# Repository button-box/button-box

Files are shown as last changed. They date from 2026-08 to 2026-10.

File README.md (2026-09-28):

# Button Box

Illustrated Button Box with a glowing blue button and family portraits

> **[Join the Button Box WhatsApp community →](https://chat.whatsapp.com/FJ8LYL79k8zEMfoiyPjLPb?mode=gi_t)**
>
> Meet other builders, share progress, and help shape the project.

**Button Box is a screen-free way for kids to send and receive WhatsApp voice
messages with family on their own.**

Button Box is an open-source hardware and software project built around one
large illuminated button. A child can record a voice note and send it to an
approved person or group. Incoming replies wait on the box until the child
presses the button to listen.

[Visit button.box](https://button.box/) ·
[Report an issue](https://github.com/button-box/button-box/issues) ·
[Testing and regression matrix](docs/testing.md)

## Latest release

[v0.1.0](https://github.com/button-box/button-box/releases/tag/v0.1.0)
includes voice messaging, video audio, recipient routing, the caregiver dashboard
and startup recovery. Tested on Raspberry Pi 4. The source release includes
a bounded updater, an installed-code manifest and checksums. Read the
[release notes](docs/releases/v0.1.0.md) before
installation. Each assembled unit requires its own physical acceptance run
before delivery.

## Build a Button Box

The complete journey is:

1. Buy the parts.
2. Assemble the hardware.
3. Prepare a Raspberry Pi OS microSD card.
4. Download this repository.
5. Connect to and inspect the Pi.
6. Provision Button Box.
7. Link WhatsApp, choose approved recipients, and optionally pair NFC tags.
8. Test the physical hardware.
9. Send, receive, play, and repeat after a reboot.

Each detailed step below ends with a **Done when** checkpoint. If the observed
result differs, stop there and troubleshoot instead of pushing ahead.

For repeatable release and per-unit verification, use the
[canonical acceptance matrix](docs/box-acceptance.md) and its
[per-unit run template](docs/box-acceptance-run-template.md).

## Step 1 — Buy your parts

### Choose a Raspberry Pi

| Board | Current status | What to expect |
| --- | --- | --- |
| **Raspberry Pi 4B** | Recommended for a first build | The public installation path has been physically exercised through Wi-Fi and WhatsApp readiness. |
| **Raspberry Pi Zero 2 W** | Supported device target; public installation gap | It needs an OTG USB hub for the USB microphone and speaker. On current `main`, provisioning stops at the Pi-4-only Comitup installer, so the fresh-card community path still needs validation. |

Do not bypass a board-safety check on a working device. If you want to help
finish the Zero 2 W path, please join the community or open a focused pull
request with the board and physical checks you performed.

### Parts with purchase links

Two versions exist — pick the parts list that matches your enclosure:
the [US parts list](#us-parts-list) or the [European parts list](#european-parts-list).
We are not affiliated with these retailers.

#### US parts list

Choose one Pi, its matching power supply, and the shared parts below.

- **Raspberry Pi Zero 2 W:** [official product and reseller page](https://www.raspberrypi.com/products/raspberry-pi-zero-2-w/?variant=raspberry-pi-zero-2-w)
- **Or Raspberry Pi 4B:** [PiShop.US](https://www.pishop.us/product/raspberry-pi-4-model-b-1gb/), [Vilros](https://vilros.com/products/raspberry-pi-4-model-b-1), or [CanaKit](https://www.canakit.com/raspberry-pi-4.html)
- **32 GB SanDisk Ultra A1 microSD card:** [Amazon](https://www.amazon.com/dp/B08L5HMJVW/)
- **TONOR G11 USB microphone:** [Amazon](https://www.amazon.com/dp/B07GVGMW59)
- **LIELONGREN 8 W USB speaker:** [Amazon](https://www.amazon.com/dp/B08QRYTPGH)
- **Pi Zero 2 W power supply:** [official Raspberry Pi 12.5 W Micro USB Power Supply](https://www.raspberrypi.com/products/micro-usb-power-supply/)
- **Or Pi 4B power supply:** [iUniker 5 V / 4 A USB-C supply](https://www.amazon.com/dp/B097P2NLVH)
- **100 mm illuminated arcade button:** [Amazon](https://www.amazon.com/dp/B072JLSH34)
- **NFC reader:** The original NFC build uses the [HiLetgo PN532 NFC/RFID module kit](https://www.amazon.com/dp/B01I1J17LC) and needs soldering. If you do not want to solder, use a Waveshare PN532 NFC HAT instead.
- **Optional M2.5 screws, nuts, and washers:** [Amazon](https://www.amazon.com/dp/B0FJ1XN2XP) — useful for mounting the Pi or NFC board inside a custom enclosure; not required for a shoebox prototype

The US reference-parts list is approximately **$150 before the enclosure,
Zero 2 W adapters, NFC tokens, shipping, and taxes**. Retailer prices and
availability change.

This is our current US reference build. Other USB speakers and microphones, and other GPIO-connected buttons, may work electrically and with the software, but each substitution is unvalidated. The Original / US printable enclosure was designed for the parts in this list. If you change the speaker, microphone, or another part, the 3D-print designs may need a revision; do not assume the substitute will fit the same case.

#### European parts list

For the [EU S8 enclosure](hardware/enclosure/README.md) (EL001 speaker).
Full parts list: [EU BOM](hardware/enclosure/eu-el001/BOM.md).

- **Raspberry Pi 4 Model B (1 GB)**
- **32 GB microSD card**
- **HOTUT USB conference mic**
- **EL-001 USB soundbar**
- **EU USB mains supply** — 15 W USB-C recommended
- **EG STARTS 100 mm illuminated arcade button, blue:** [Amazon](https://www.amazon.com/dp/B072JLSH34)
- **Waveshare PN532 NFC HAT**
- **Full-size NFC cards**
- **Mounting fasteners, hook-up wire, and PLA feedstock** for the printed enclosure

You will also need:

- **NFC cards or tokens:** [Adafruit 13.56 MHz Classic 1K card](https://www.adafruit.com/product/359), which Adafruit states is tested with PN532 readers
- **Hook-up wire and insulated connectors:** [0.25-inch arcade-button wire pairs](https://www.adafruit.com/product/3838) and an [assorted 2.8/4.8/6.3 mm spade-connector kit](https://www.adafruit.com/product/4748) are examples; confirm the terminal sizes on your button before ordering
- **A microSD-card reader that fits your computer:** [USB-C example](https://www.adafruit.com/product/5212) or [USB-A example](https://www.adafruit.com/product/939)
- **For Pi Zero 2 W, a suitable OTG USB hub**, powered if your selected audio devices require it. This [micro-USB OTG mini hub](https://www.adafruit.com/product/2991) is an example only; it has not yet been physically validated with the reference microphone and speaker.
- **An enclosure:** use a [printable enclosure](hardware/enclosure/README.md) — available in US and European versions, each with its own parts list — a shoebox, or another sturdy, non-conductive container.
- **A computer with internet access** for preparing and provisioning the Pi
- **A new, dedicated phone number for the Button Box WhatsApp account.** Add a line or eSIM through your mobile provider, activate it in the WhatsApp mobile app on a phone, and then link Button Box as a companion device.

### What the build takes

- Comfort following terminal commands one step at a time, or access to an AI
  coding agent that can guide you
- Raspberry Pi Imager and permission to erase a microSD card
- Temporary Wi-Fi, Ethernet, USB Ethernet, or Internet Sharing during setup
- Time to assemble, install, test each component, and troubleshoot an alpha
  build

> [!NOTE]
> The public product is **Button Box**. Some commands, package names, hostnames,
> and services still use the historical internal name `messagebox`. Use those
> exact names for now.

### Once your parts arrive — build with an agent

Point a capable coding agent at this repository and give it this prompt:

```text
Help me build a Button Box from this repository:
https://github.com/button-box/button-box

Read README.md and AGENTS.md before giving instructions. First ask whether I
have a Raspberry Pi Zero 2 W or Raspberry Pi 4B. Work one numbered step at a
time and wait for me to confirm each physical result.

The goal is to have a working box that sends and receives voice messages.
Do not ask me to paste credentials, phone numbers, WhatsApp identifiers, Wi-Fi
details, NFC identifiers, recordings, or authentication files into the chat.
Stop if my physical result differs from the README checkpoint.
```

A helpful agent should:

- identify the Pi model before choosing parts or commands
- explain each command before asking the builder to run it
- use each **Done when** result as a checkpoint
- stop when physical evidence differs from the guide
- never guess a disk, network address, GPIO connection, or WhatsApp recipient
- preserve a working card or device rather than experimenting on it
- redact private information before helping prepare an issue

Button Box uses [wacli](https://github.com/openclaw/wacli), an unofficial
WhatsApp Web client. Button Box is not affiliated with or endorsed by WhatsApp
or Meta.

## Step 2 — Assemble the hardware

A shoebox or another sturdy, non-conductive box is an alternative to 3D printing the enclosure. Whichever enclosure you use, secure the electronics, provide ventilation, and protect the cables from strain and loose metal.

The default public GPIO configuration is:

| Connection | BCM/board name |
| --- | --- |
| Record button | BCM GPIO 17 |
| Button LED | BCM GPIO 26 |
| PN532 reset | D20 |
| PN532 request | D16 |
| PN532 data | I²C |

> [!CAUTION]
> A [community wiring diagram](hardware/README.md#community-wiring-diagram) is available,
> with different PN532 reset/request pins and configuration notes. It has not
> been physically validated. The pin list above remains the software default. Confirm button voltage, LED current limiting, connector sizes, Pi
> pin numbering, and PN532 I²C mode before applying power. Never connect or
> disconnect GPIO wiring while the Pi is powered.

For the printable prototype, download the [top](hardware/enclosure/button-box-enclosure-top.stl)
and [bottom](hardware/enclosure/button-box-enclosure-bottom.stl) enclosure files.

**Done when:** the unpowered assembly is mechanically secure, every connection
has been independently checked, and there are no loose conductors or shorts.

## Step 3 — Prepare the microSD card

Install the current [Raspberry Pi Imager](https://www.raspberrypi.com/software/)
on your computer.

In Imager:

1. Select your exact Raspberry Pi model.
2. Select **Raspberry Pi OS Lite (64-bit)** based on Debian 13.
3. Choose the correct microSD card.
4. Set a hostname such as `button-box-001`. Existing `message-box-*` hostnames remain supported.
5. Create a non-root administrator such as `admin`.
6. Enable SSH, preferably with a dedicated public key.
7. Give the Pi temporary internet access through Imager Wi-Fi settings,
   Ethernet, USB Ethernet, or Internet Sharing.
8. Leave Raspberry Pi Connect disabled unless you deliberately need it.
9. Confirm the exact removable card before writing.

> [!CAUTION]
> Writing an operating-system image erases the selected card. Confirm its
> physical identity, capacity, and partitions before continuing.

> [!IMPORTANT]
> Imager remembers customisation from previous runs, including the Wi-Fi network
> name and password, and pre-fills them. When re-flashing after a Pi that failed
> to appear, retype the Wi-Fi name rather than accepting the remembered value: a
> typo carries forward silently, and the retained setting is most likely to bite
> exactly when you are trying to correct it.

Insert the verified card into the powered-off Pi, connect temporary networking,
and power it on.

**Done when:** the Pi boots and responds at its `.local` hostname.

## Step 4 — Download Button Box on your computer

On the computer that will provision the Pi:

```sh
git clone https://github.com/button-box/button-box.git
cd button-box
```

Confirm the checkout and required host commands:

```sh
git status --short --branch
ssh -V
rsync --version
```

On macOS, use a modern GNU rsync rather than the built-in `openrsync`:

```sh
brew install rsync
PATH="/opt/homebrew/bin:$PATH" rsync --version
```

**Done when:** the repository is on your computer and SSH plus modern rsync are
available.

## Step 5 — Connect to and inspect the Pi

Replace `admin` and the hostname below if you chose different values:

```sh
ssh admin@button-box-001.local
```

On the Pi, verify the model, architecture, and operating-system release:

```sh
tr -d '\0' </proc/device-tree/model
uname -m
grep -E '^(PRETTY_NAME|VERSION_CODENAME)=' /etc/os-release
```

Expected architecture: `aarch64`

Expected Debian codename: `trixie`

Exit the Pi:

```sh
exit
```

**Done when:** the detected model matches your chosen board and the supported
64-bit OS is running.

## Step 6 — Install Button Box

> [!IMPORTANT]
> Continue with the automated public installer on Raspberry Pi 4B. On current
> `main`, the install stops on Pi Zero 2 W because `scripts/install/comitup.sh`
> is explicitly validated only on Pi 4. Zero 2 W runtime support remains, but
> its fresh-card installation path needs a tested repository change.

From the repository root on your computer:

```sh
./scripts/provision.sh admin@button-box-001.local
```

On macOS with Homebrew rsync:

```sh
PATH="/opt/homebrew/bin:$PATH" ./scripts/provision.sh admin@button-box-001.local
```

The script transfers an explicit set of installation files, installs Button Box
in fixed system paths, and leaves runtime and onboarding services stopped.

**Done when:** setup prints `BUTTON BOX SETUP COMPLETE` without an error.

## Step 7 — Choose an onboarding path

### Path A: terminal-assisted DIY build

This is currently the shortest path to a working experimental box. It uses the
Pi's temporary network connection and does not use the consumer Wi-Fi portal.

Run from your computer:

```sh
ssh -t admin@button-box-001.local messagebox-dev-onboard
```

The guided workflow will:

1. Link or verify WhatsApp.
2. Display recent chats with their exact WhatsApp identifiers.
3. Configure the first approved recipient.
4. Optionally configure the private dashboard.
5. Offer to test the physical hardware.
6. Enable and start the selected runtime services.

Enter phone numbers and other private values directly into the terminal when
prompted. Do not paste them into an agent conversation or GitHub issue.

**Done when:** the workflow reports WhatsApp ready, the exact intended recipient
is configured, the selected hardware tests pass, and the selected services are
enabled and started.

### Path B: browser Wi-Fi and WhatsApp onboarding

This path is the intended household experience from Wi-Fi through normal
runtime activation.

Initialize the protected onboarding identity:

```sh
ssh -t admin@button-box-001.local sudo messagebox-init-wifi-onboarding
```

Record the displayed hotspot name, hotspot password, and setup URL privately.
Then arm onboarding:

```sh
ssh -t admin@button-box-001.local sudo messageboxctl reset-wifi
```

On a phone:

1. Join the Button Box setup hotspot.
2. Open the supplied setup URL.
3. Select home Wi-Fi and enter its password.
4. Rejoin home Wi-Fi when the setup hotspot disappears.
5. Open the same `http://button-box-001.local/` address.
6. Link WhatsApp with the displayed phone code.
7. Choose a default recipient and complete the guided two-way voice test.
8. Allow any additional recipients and optionally pair NFC tags.
9. Skip NFC setup or choose Done to activate messaging.

NFC is optional. A zero-tag setup routes new standalone messages to the default
recipient without depending on the reader. Once any tag is mapped, unsafe NFC
health or unknown tag state blocks rather than silently choosing the default.
Path A remains the terminal-assisted developer workflow; the two paths are not
continuations of one another.

**Done when:** the browser reports that Button Box is ready and the intended
default and optional tag mappings pass the physical scenarios below.

## Step 8 — Test the hardware

The terminal-assisted onboarding offers this test automatically. To run it
separately, connect to the Pi and run it as the `messagebox` service user:

```sh
ssh -t admin@button-box-001.local
sudo -u messagebox -H /opt/messagebox/dev/hardware-test.sh
```

The interactive test checks:

- internet access
- speaker
- microphone and playback
- button LED
- record button
- PN532 reader and an NFC card
- WhatsApp authentication

It does not send a WhatsApp message or reveal NFC identifiers.

**Done when:** every installed component passes, or any deliberately omitted
component is documented.

## Step 9 — Start the box and complete the first message loop

Check the selected services:

```sh
messageboxctl services
messageboxctl status
```

With an approved recipient expecting the test:

1. Hold the physical button and record a short message.
2. Release the button and follow the box's confirmation behavior.
3. Confirm that the message reaches the intended recipient.
4. Ask the recipient to reply with a voice note.
5. Confirm the box queues and plays the reply.
6. Reboot the Pi.
7. Repeat a short send-and-receive check.

**Done when:** the real button, LED, microphone, speaker, network, WhatsApp
account, recipient routing, send, reply, playback, and reboot behavior all pass
on the physical device.

## What works today

| Capability | Status | What that means |
| --- | --- | --- |
| Device runtime | **Experimental** | Recording, sending, receiving, playback, fail-closed recipient routing, and NFC support exist. |
| Raspberry Pi 4B | **Supported** | A brand-new-card installation has been physically completed through Wi-Fi and WhatsApp onboarding. |
| Raspberry Pi Zero 2 W | **Supported device target; install gap** | The device target is supported, but the current public provisioning path still contains a Pi-4-only Comitup gate and needs clean-install validation. |
| Wi-Fi and WhatsApp browser onboarding | **Experimental** | The physical Pi 4B flow has reached verified WhatsApp readiness. |
| Recipient and NFC browser onboarding | **Experimental** | Repository coverage is included; fresh-Pi NFC and final activation acceptance are still required. |
| Enclosure | **Prototype** | Printable [top and bottom STL files](hardware/enclosure/README.md) are available. |
| Complete first-message journey from public instructions | **In progress** | Physical proof is still needed for recipient setup, NFC where used, runtime startup, send, reply, playback, and reboot using only this README. |

Automated tests and repository review do not prove a physical Pi, phone, Wi-Fi,
GPIO, NFC, audio, or WhatsApp journey. Please say exactly what you tested when
reporting success or opening a pull request.

## Troubleshooting

### The Pi hostname does not resolve

Confirm that the Pi and computer are on a compatible network. Try the hostname
you set in Imager. If necessary, inspect your router's device list rather than
guessing a fixed IP address.

Distinguish "not on the network" from "name not resolving" before changing
anything. A Pi with a mistyped Wi-Fi name boots perfectly — solid red LED,
flickering green, filesystem resized — and simply never joins. Scan your subnet
for a Raspberry Pi MAC prefix (`dc:a6:32`, `e4:5f:01`, `b8:27:eb`):

```sh
arp -a | grep -iE 'dc:a6:32|e4:5f:01|b8:27:eb'
```

If nothing answers, the Pi is not on the network and the Wi-Fi settings are the
place to look.

You can check those settings **before first boot**. Raspberry Pi Imager writes
them to the card's FAT boot partition as cloud-init files — `user-data`,
`network-config` and `meta-data`, with `ds=nocloud` and
`cfg80211.ieee80211_regdom=<CC>` in `cmdline.txt` — all readable from any
computer. After first boot they are consumed, and the live configuration lives on
the ext4 root partition, which macOS and Windows cannot read; at that point
re-flashing is the practical fix.

### SSH says `Permission denied (publickey)`

Confirm which SSH identity is being offered:

```sh
ssh -v admin@button-box-001.local
```

If you created a dedicated key, select it explicitly in your SSH configuration
or with `ssh -i`.

### Provisioning says `scripts/setup.sh: No such file or directory`

On macOS, confirm that `rsync --version` reports modern GNU rsync and rerun
provisioning with Homebrew first in `PATH`.

### The installer says Comitup is validated only on Raspberry Pi 4

You are installing on a different Pi model. This is the current public Zero 2 W
installation gap described above. Do not edit out the model check on a working
device; follow or help with the clean-install validation work instead.

### The setup hotspot does not appear

Keep a separate recovery connection when possible. Check onboarding services:

```sh
messageboxctl logs onboarding
```

Do not share unredacted output publicly.

### The wrong Wi-Fi password was entered

The onboarding flow should return to a retryable hotspot state. If recovery is
required, `sudo messageboxctl reset-wifi` removes saved infrastructure Wi-Fi
profiles and restarts onboarding.

### WhatsApp pairing expires

Return to the home-network setup page and request another code. An interrupted
attempt should not promote an unverified authentication store.

### A service will not start

Check:

```sh
messageboxctl services
messageboxctl status
```

Before posting logs, remove phone numbers, WhatsApp identifiers, Wi-Fi details,
NFC identifiers, recordings, private addresses, and authentication state.

## Privacy and security

Button Box stores configuration, approved contacts, WhatsApp authentication
state, and queued audio locally on the Pi. These files must never be committed
to Git or copied into public diagnostics.

The dashboard has no login. Leave it disabled unless you understand the network
exposure. If enabled, bind it only to a private address you control.

Do not put security-sensitive details in a public issue. Contact the maintainers
through the community and ask for a private disclosure channel first.

## Updating and recovery

Button Box uses fixed installed paths rather than running directly from the
repository checkout. Re-run the provisioning script to install a reviewed
update.

Before updating a working physical box:

1. Confirm the exact source commit.
2. Stop Button Box services.
3. Preserve rollback material.
4. Provision the reviewed tree.
5. Verify services and real device behavior.
6. Keep repository validation separate from physical acceptance.

## Get help

Use [GitHub Issues](https://github.com/button-box/button-box/issues) for
reproducible bugs and documentation problems, or
[join the community](https://chat.whatsapp.com/FJ8LYL79k8zEMfoiyPjLPb?mode=gi_t)
for builder discussion.

A useful issue includes:

- Pi model
- Raspberry Pi OS release
- Button Box commit
- the numbered build step
- expected result
- actual result
- sanitized error text

Never include credentials, phone numbers, WhatsApp identifiers, NFC identifiers,
recordings, private addresses, or authentication files.

## Contributing

Community contributions are welcome, especially:

- beginner-tested installation instructions
- Pi Zero 2 W and Pi 4B build photographs
- wiring and assembly diagrams
- enclosure designs
- accessibility improvements
- recovery and troubleshooting guides
- hardware compatibility reports
- focused tests and fixes

Before opening a pull request:

```sh
make check
```

State clearly which checks were automated and which Pi, phone, network, audio,
GPIO, NFC, Wi-Fi, or WhatsApp behaviors were physically tested.

## Repository map

- `messagebox/`: device runtime, dashboard, and onboarding package
- `messagebox/dashboard/static/`: private dashboard assets
- `messagebox/onboarding/static/`: household onboarding portal
- `scripts/`: installation, provisioning, and command wrappers
- `scripts/dev/`: experimental developer onboarding and hardware checks
- `systemd/`: device services and runtime target
- `config/`: public configuration and pinned dependencies
- `hardware/`: [hardware list and printable enclosure files](hardware/README.md)
- `sounds/`: audio licensing requirements and future assets
- `tests/`: synthetic unit and contract tests
- `docs/`: architecture, installation, testing, and developer documentation

## License and acknowledgements

Button Box software is licensed under the [MIT License](LICENSE). Third-party
hardware, software, and audio remain subject to their own licenses and terms.

Button Box uses [wacli](https://github.com/openclaw/wacli) and
[Comitup](https://github.com/davesteele/comitup). It is not affiliated with or
endorsed by WhatsApp or Meta.
--- sha: f40a0195ab57e6bc33c950bdb755f7ea276145e4 ---

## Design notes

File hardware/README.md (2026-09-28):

# Hardware

## BOM

Two build versions exist: the **US reference build** below (pairs with the [Original / US enclosure](enclosure/README.md)), and the **EU build** ([EU BOM](enclosure/eu-el001/BOM.md), pairs with the [EU S8 enclosure](enclosure/README.md)).

| Item | Approx. price | Sources |
| --- | ---: | --- |
| Raspberry Pi 4 Model B, 1 GB RAM | $40 | [PiShop.US](https://www.pishop.us/product/raspberry-pi-4-model-b-1gb/), [Vilros](https://vilros.com/products/raspberry-pi-4-model-b-1), [CanaKit](https://www.canakit.com/raspberry-pi-4.html) |
| SanDisk 32 GB Ultra A1 Class 10 microSDHC card | $24 | [Amazon](https://www.amazon.com/dp/B08L5HMJVW/) |
| TONOR G11 omnidirectional USB microphone | $30 | [Amazon](https://www.amazon.com/dp/B07GVGMW59) |
| LIELONGREN 8 W USB computer speaker | $16 | [Amazon](https://www.amazon.com/dp/B08QRYTPGH) |
| iUniker 5 V / 4 A USB-C Pi 4 power supply | $10 | [Amazon](https://www.amazon.com/dp/B097P2NLVH) |
| EG STARTS 100 mm illuminated arcade button, blue | $11 | [Amazon](https://www.amazon.com/dp/B072JLSH34) |
| VGBUY 750-piece M2.5 screw, nut, and washer kit | $10 | [Amazon](https://www.amazon.com/dp/B0FJ1XN2XP) |
| HiLetgo PN532 NFC/RFID V3 module kit | $9 | [Amazon](https://www.amazon.com/dp/B01I1J17LC) |
| **Approx. total** | **$150** | |

The **Approx. total** covers only the rows above. A complete build also needs the
NFC cards or tokens, hook-up wire and insulated connectors, a microSD card reader,
and an enclosure, all listed under "You will also need" in the
[README](../README.md). Nothing in the table above connects the button to the
GPIO header.

The card reader is easy to overlook: many current laptops have no SD slot at all,
and without one there is no way to write the card. A reader that takes microSD
directly, such as [this USB-C one](https://www.amazon.com/dp/B0DQ71G4G4), avoids
also needing the card's full-size adapter.

The table lists the HiLetgo PN532 module, but `messagebox/nfc.py` is written for a
Waveshare PN532 NFC HAT: it passes a `req` pin, the PN532's P32 "H_Request", and
the `config/env.example` defaults of `D20` and `D16` are that HAT's documented
jumper positions. A HiLetgo build needs soldering and its own pin mapping.

The parts above are the reference build. Other USB speakers and microphones, and other GPIO-connected buttons, may work electrically and with the software, but each substitution is unvalidated. The printable enclosure was designed for the parts in this list. If you change the speaker, microphone, or another part, the 3D-print designs may need a revision; do not assume the substitute will fit the same case.

## Community wiring diagram

This community-contributed diagram shows a Raspberry Pi 40-pin header, an
arcade-button switch, a button LED, and a PN532 module in I²C mode. It is a
visual reference, not a physically validated reference build.

> [!CAUTION]
> The image omits LED current limiting. Do not connect a bare LED directly to
> a GPIO: use a suitable series resistor, and an appropriate driver if the
> illuminated button requires more current or a higher voltage than GPIO can
> provide. The PN532 reset/request connections also differ from the software
> defaults; use the configuration below only for this wiring. Disconnect Pi
> power before connecting or changing any wires.

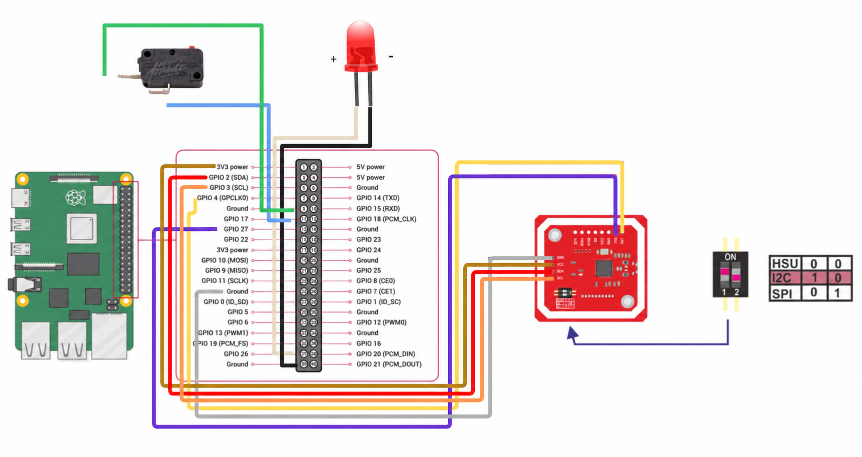
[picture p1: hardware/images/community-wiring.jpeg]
Community wiring diagram for the Raspberry Pi button, LED, and PN532 I²C module


### Connections shown

BCM GPIO numbers are not physical header pin numbers.

| Connection | Raspberry Pi signal | Physical header pin | Wire in diagram |
| --- | --- | ---: | --- |
| Button switch | BCM GPIO 17 | 11 | Blue |
| Button switch ground | GND | 9 | Green |
| LED positive, through suitable current limiting/driver | BCM GPIO 26 | 37 | Beige |
| LED negative | GND | 39 | Black |
| PN532 VCC | 3.3 V | 1 | Brown |
| PN532 GND | GND | 25 | Grey |
| PN532 SDA | BCM GPIO 2 / SDA | 3 | Red |
| PN532 SCL | BCM GPIO 3 / SCL | 5 | Orange |
| PN532 RST | BCM GPIO 4 / D4 | 7 | Yellow |
| PN532 IRQ | BCM GPIO 27 / D27 | 13 | Purple |

Use the switch's COM and normally-open (NO) terminals; identify them from the
actual switch markings rather than their position in the picture. On the
pictured PN532 module, I²C mode is switch **1 ON, 2 OFF**. Check the markings
and documentation for your exact board, including its reset pin and supply
requirements; other PN532 modules and HATs may differ.

### Configuration for this diagram

For this wiring, set the following values in `/etc/messagebox/env`:

```sh
MSGBOX_BUTTON_PIN=17
MSGBOX_LED_PIN=26
MSGBOX_NFC_RESET_PIN=D4
MSGBOX_NFC_REQUEST_PIN=D27
```

The repository defaults in [`config/env.example`](../config/env.example) are
instead **D20** for reset (physical pin 38) and **D16** for request (physical
pin 36). If using those defaults, connect the yellow and purple wires to
those pins instead. Do not combine one wiring layout with the other settings.

Before applying power, independently check header orientation, every
connection, LED current limiting, and the module's I²C mode. Then follow the
[hardware test](../README.md#step-8--test-the-hardware). The image and the
configuration comparison have been reviewed against the repository; physical
GPIO, LED, and NFC operation with this exact layout has not been verified as
part of this contribution.

## Reference button terminals

The EG STARTS 100 mm illuminated button has **four** spade terminals on one
carrier, and they are not interchangeable:

| Terminals | Size | What they are |
| --- | --- | --- |
| `COM` and `NO` | 4.8 mm | Microswitch — the two narrower blades |
| Lamp + and - | 6.3 mm | LED lamp — the two wider tabs with round holes |

The seller states the two sizes. The moulded `COM` and `NO` markings sit between
terminals rather than beside them, so they do not reliably identify which tab is
which.

Connecting the switch wires to the lamp pair produces a silent failure. The switch
still clicks, the wiring is continuous, the GPIO is configured correctly, and
nothing registers.

The lamp is polarity-sensitive: reversed, it stays dark rather than failing.

### Lamp circuit, reference part only

The reference button's lamp module has been observed working **directly from BCM
GPIO 26** (physical pin 37), with its return on a ground pin, driven by
`messagebox-button.service`. It also lights brightly at 5 V. The module has
internal current limiting, which is why the general caution against driving a bare
LED from a GPIO does not apply to this particular part.

Current draw was not measured. Verify your own lamp before assuming the same; a
substitute may need a transistor and a separate supply.

## PN532 NFC HAT configuration

A Waveshare-style PN532 NFC HAT **does not ship in I²C mode**. Out of the box the
DIP switches for `SCL` and `SDA` are off and both mode jumpers sit on `L`, which
selects UART. In that state the chip does not appear on the I²C bus at all: a bus
scan returns no addresses, rather than an unresponsive device.

For the repository defaults of `MSGBOX_NFC_RESET_PIN=D20` and
`MSGBOX_NFC_REQUEST_PIN=D16`:

| Setting | Value |
| --- | --- |
| DIP switches 5 (`SCL`) and 6 (`SDA`) | **ON** |
| DIP switches 1-4 (SPI) and 7-8 (UART) | OFF |
| `I0` jumper | **H** |
| `I1` jumper | **L** |
| `RSTPDN` jumper | **D20** |
| `INT0` jumper | **D16** |

The board prints its own mode table: UART is `I1=L, I0=L`; I²C is `I1=L, I0=H`;
SPI is `I1=H, I0=L`.

Confirm the reader before enabling the NFC service. A HAT in I²C mode answers at
address `0x24`:

```sh
/opt/messagebox/venv-nfc/bin/python -c "
import board, busio, time
i2c = busio.I2C(board.SCL, board.SDA)
while not i2c.try_lock(): time.sleep(0.01)
print([hex(a) for a in i2c.scan()]); i2c.unlock()"
```

An empty result means the interface selection is wrong. `0x24` present but
unresponsive points at the reset and request jumpers instead.

These HATs commonly have a stacking header, so the button and lamp can use the
pass-through pins above the board.

## Enclosure

The prototype Button Box enclosure has two printable parts:

- [Top](enclosure/button-box-enclosure-top.stl)
- [Bottom](enclosure/button-box-enclosure-bottom.stl)

See the [enclosure notes](enclosure/README.md) for dimensions.
--- sha: e7db09144e54df7cedc67581782deb3ab0f056a4 ---

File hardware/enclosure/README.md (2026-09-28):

# Button Box enclosure

## Print files

- 🇪🇺 **European — EU S8 (EL001 speaker):** [base-print.stl](eu-el001/exports/base-print.stl) · [lid-print.stl](eu-el001/exports/lid-print.stl) — parts list: [EU BOM](eu-el001/BOM.md) · [all exports](eu-el001/exports) · [details, STEP source and rebuild](eu-el001/README.md)
- 🇺🇸 **Original / US — two-part prototype:** [Top](button-box-enclosure-top.stl) · [Bottom](button-box-enclosure-bottom.stl) — parts list: [hardware BOM](../README.md#bom)

The meshes share a 192 mm by 120 mm footprint when interpreted in millimeters.
The top is approximately 74.5 mm tall and the bottom is approximately 20.5 mm
tall.

Measured from `button-box-enclosure-top.stl` (original / US), for checking parts before printing:

- Button opening approximately 87-93 mm across, centred 43 mm from the middle
  along the long axis
- Two slots near one corner, 12 x 2 mm and 8 x 2 mm
- 13 mm overlap between the two parts; 82 mm assembled height
- Roughly 270 g of PLA for both parts together

The EG STARTS 100 mm button in the BOM needs an 88 mm mounting hole and is 95 mm
deep from the top of the plunger to the bottom of the microswitch. Most of that
depth sits above the panel, but check it against your own layout.

A shoebox or another sturdy, non-conductive box is an alternative to 3D printing these parts. Secure the electronics, provide ventilation, and protect the cables from strain and loose metal.
--- sha: 86d6411ef705890f58e75a148f967c72f4eeea31 ---
--- sha: 8a83a43534053fc69038b1746a9f8b46aad8c4d3 ---
--- sha: a1c7696f3fe3921da527290ec3dc99f34ad17d34 ---

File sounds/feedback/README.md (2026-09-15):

# Send confirmation

`sent-swoosh.wav` is an original, synthesized three-second paper-plane swoosh:
a soft intake, sustained airy acceleration and a playful three-note landing, 48 kHz,
16-bit mono PCM. It contains no sampled Apple or other third-party audio.
It is distributed under the repository's source-code license. Reproduce it with
`python3 scripts/dev/generate-send-swoosh.py`.
The signal is band-limited and normalized to at most -6 dBFS peak, with smooth
endpoints and an audible tail rather than silence padding. This limits digital
peaks; perceived loudness and comfort still need an actual-speaker check.

The button service queues this cue only after WhatsApp's send command succeeds
and local outbox completion succeeds, for both guided and hold/release modes.
It means accepted for sending, not delivered or listened to. The old immediate
hold/release "sent" beep at outbox enqueue is removed.

The main button loop plays the cue when idle, using the caregiver's current
speaker volume. The sender worker never waits for the sound. A new button press
stops this cue and passes through the normal press debounce, without requiring
a second press. The player is stopped/reaped before the next audio operation;
a five-second watchdog bounds a stuck player. This cue does not interrupt
recording, prompts, or incoming playback. Their normal press handling is unchanged.
Cues older than 30 seconds are discarded to avoid confusing them with a newer
recording. Pending cues are transient and are not replayed after restart.
A missing asset or playback failure does not retry the WhatsApp message.

Before release, check volume and perceived meaning on the actual speaker,
both recording modes, failed/offline sends, and sends completing during playback.

## Candidate audition (after explicit test-box deployment approval)

1. Verify the exact candidate file hashes and an idle box, with no recording,
   prompt, or incoming playback active. Keep the existing release unchanged
   until that separate approval; a Mac preview is not a box-speaker pass.
2. Start a bounded room capture with three quiet baseline seconds. Send one
   synthetic test reply to the authorized test chat using the normal flow.
3. Let the success swoosh finish: it should sound like one smooth, roughly
   three-second flight, with no harsh peak or repeated notification.
4. Repeat one authorized test send. During its swoosh, press the button once
   deliberately. The cue should stop promptly and that same press should begin
   the normal configured interaction; check that audio does not overlap and
   delivery was not delayed or duplicated. Finish/cancel the resulting test
   interaction normally, preserving queued messages.
5. Record actual phone delivery separately from the accepted-send cue. Stop
   capture and retain only sanitized measurements, then delete room audio.

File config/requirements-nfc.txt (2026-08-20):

adafruit-circuitpython-pn532==2.4.9
Adafruit-Blinka==9.2.0
lgpio==0.2.2.0

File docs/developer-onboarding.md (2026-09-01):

# Developer onboarding

## Consumer and developer boundaries

Consumer setup verifies Wi-Fi and WhatsApp, selects an initial default
recipient, proves one received-and-replied voice exchange, and then exposes a
recipient manager where the default can be changed, optionally pairs NFC tags,
and then activates the normal runtime. Zero, partial, or full tag coverage is
valid.
During the proof it starts only the scoped setup sync, poller, and guided
button target; the normal `messagebox.target` remains gated. Consumer completion
enables button, sync, poller, NFC reader, and the canonical dashboard. With no
card mappings, NFC cannot affect the default-recipient route.

`messagebox-dev-onboard` is an independent prototype workflow. It pairs
WhatsApp, configures contacts and the dashboard, tests hardware, and can start
runtime services; it does not configure Wi-Fi. Development devices may use a
valid lowercase ID instead of the numbered shipping hostname defined in
[Installation](installation.md).

## Internet access for a fresh card

A fresh Pi needs temporary Wi-Fi, routed Ethernet, or macOS Internet Sharing
during setup. For a direct cable from a Mac, open **System Settings > General >
Sharing > Internet Sharing**, share Wi-Fi to the USB Ethernet adapter, and turn
sharing on. Reconnect the cable or reboot the Pi to request a DHCP lease.

Provision from the repository root on the development computer:

```sh
./scripts/provision.sh admin@button-box-001.local
```

Provisioning refuses to connect to the Pi if any required prompt is absent.
This keeps a clean card from reaching recipient onboarding with an unusable
button service. Pass `--guided-prompts DIR` to test an alternate licensed set.

Use the Pi's `.local` hostname instead of assuming a fixed address. Turn
Internet Sharing off before testing consumer Wi-Fi onboarding.

## Reprovision a test box

On a disposable test box reachable over SSH, run:

```sh
./scripts/dev/reprovision.sh admin@button-box-001.local
```

The helper requires confirmation. It preserves the operating system, packages,
users, NetworkManager profiles, contacts, incoming queue, and hardware
configuration. It deletes generated onboarding credentials and state, WhatsApp
authentication, and pending outbound recordings so they cannot be sent through
a newly paired account. It is not a clean-card installation test.

## Reset consumer Wi-Fi

Follow [Installation](installation.md) for first-time initialization and
manufacturer handoff. To return an initialized test Pi to onboarding mode, run:

```sh
sudo messageboxctl reset-wifi
```

`reset-wifi` deletes every saved infrastructure Wi-Fi profile, stops runtime
services, resets onboarding state, enables onboarding for future boots, and
starts the setup hotspot. It does not delete contacts or queued incoming
messages.

## Standalone developer flow

Run locally as a non-root sudo-capable administrator:

```sh
messagebox-dev-onboard
```

Or run it remotely:

```sh
ssh -t admin@button-box-001.local messagebox-dev-onboard
```

The flow stops Button Box services before configuration and testing. If it
exits early, they may remain stopped. It shows synced chats and their exact JIDs.
To list them again later, run:

```sh
sudo -u messagebox -H env \
  WACLI_STORE_DIR=/var/lib/messagebox/wacli \
  WACLI_SYNC_MAX_DB_SIZE=2GB \
  /usr/local/bin/wacli --read-only chats list --limit 200
```

Use the exact `CHAT_JID` shown. Group JIDs look like `123456789@g.us`;
direct-chat JIDs look like `15551234567@s.whatsapp.net`. Never infer a JID from
a display name or phone number.

## Contacts and routing

These examples use synthetic JIDs:

```sh
messagebox-contact add "Family" 123456789@g.us
messagebox-contact enroll 123456789@g.us
messagebox-contact list
messagebox-contact remove 123456789@g.us
```

`add` arms enrollment for the first NFC card for five minutes. Both
`messagebox-nfc.service` and `messagebox-button.service` must be active, with
`MSGBOX_NFC_DETECTION_BEEP` enabled. Use `--no-card` only when deliberately
adding a contact without a card:

```sh
messagebox-contact add "Direct example" 15551234567@s.whatsapp.net --no-card
```

The contact store has an explicit default recipient. With no valid card
selection, standalone recordings route to that default. A recognized card can
override it within the selection window (30 seconds by default). A missing
default or an unknown or invalid card state blocks rather than guessing or
rerouting. Replies to incoming messages always use the exact originating chat.

## Service control

`messageboxctl` wraps common systemd and journal operations. Run
`messageboxctl --help` for the full command list. Common commands are:

```sh
messageboxctl services
messageboxctl status
messageboxctl logs poller
messageboxctl logs onboarding
sudo messageboxctl restart
sudo messageboxctl enable button sync poller nfc
sudo messageboxctl disable dashboard
```

Service names are `button`, `sync`, `poller`, `dashboard`, and `nfc`. Consumer
voice proof uses `messagebox-onboarding-voice.target` and
`messagebox-onboarding-button.service`; they are not operator-selectable runtime
services. Tag pairing uses `messagebox-onboarding-nfc.service`, not the normal
runtime NFC daemon.

## Hardware and dashboard

The hardware test checks network access, speaker, microphone, LED, button,
PN532/card detection, and WhatsApp authentication. It does not send a message or
display NFC IDs. Run it directly only in an interactive terminal as the
`messagebox` service user:

```sh
sudo -u messagebox -H /opt/messagebox/dev/hardware-test.sh
```

The dashboard has no login. Prefer binding `MSGBOX_DASH_BIND` to the Pi's
Tailscale IPv4 address. Binding to `0.0.0.0` exposes it on every connected
network; use that setting only on a trusted network. An empty bind keeps the
dashboard unavailable.

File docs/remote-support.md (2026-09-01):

# Remote support with Tailscale

Tailscale can give a shipped Button Box a private route back to its operator.
It does not make an offline box reachable and it does not replace OpenSSH keys,
local recovery, backups, or tested application releases.

Remote support is optional. Enrolling a household box gives authorized tailnet
members a path to its SSH service, which can expose private device state. Get
the household's consent, restrict tailnet membership and access rules, and do
not expose the dashboard or any service to the public internet. The Button Box
adds no heartbeat, but the Tailscale client itself exchanges connection and
diagnostic metadata with Tailscale's control plane; include that in the
household's consent decision.

## Provision before shipping

Prepare ordinary OpenSSH access first. The administrator must be non-root,
must have the operator's public key in `~/.ssh/authorized_keys`, and must have
passwordless `sudo` for this unattended support model. Protect the operator's
private key with a passphrase and keep a second authorized computer or recovery
key available.

From a clean, reviewed repository checkout on a computer that can currently
reach the Pi over LAN or Ethernet, run:

```sh
./scripts/provision-tailscale.sh admin@button-box-001.local
```

The helper:

1. Refuses root, malformed targets, and devices outside the supported
   `button-box-*` and legacy `message-box-*` hostname patterns.
2. Installs Tailscale from its signed official Debian 13 repository.
3. Opens Tailscale's interactive browser authorization when the device is not
   already enrolled.
4. Discovers the device's exact MagicDNS name, stores it only in the device's
   private runtime configuration, and enables Tailscale Serve on HTTPS 443 to
   the dashboard's loopback listener.
5. Leaves Tailscale SSH, Funnel, subnet routing, and exit-node features
   disabled. An existing conflicting Serve mapping on HTTPS 443 is preserved
   and causes provisioning to stop.
6. Holds the package so upgrades happen during an attended support session.

No reusable Tailscale auth key is accepted or stored. The device and Tailscale
hostnames must match so the dashboard can validate one exact private origin.

Keep the LAN session open. Move the operator computer to a genuinely different
network, such as a phone hotspot, then use the address printed by the helper:

```sh
ssh admin@100.x.y.z
```

That is ordinary OpenSSH carried over Tailscale. `tailscale ssh` is deliberately
not used, so every support computer still needs an authorized OpenSSH key.
Confirm both the remote path and the original LAN fallback before shipping.

The helper also prints a stable private dashboard URL such as:

```text
https://button-box-001.example-tailnet.ts.net/
```

On a phone or computer signed in to the authorized tailnet, open that URL in a
browser. Tailscale provisions its certificate and keeps the Serve mapping over
reboots. The dashboard is not made public: Funnel is never enabled. Bare
Tailscale IP addresses and unrecognized `.ts.net` names are not accepted as
dashboard browser origins.

By default, Tailscale device keys can expire and an expired remote box stops
accepting tailnet connections. For this trusted, unattended device, open its
entry on the **Machines** page and deliberately choose **Disable key expiry**.
This reduces security: revoke or remove the device immediately if the box is
lost, replaced, or no longer supported. Do not use
`tailscale up --force-reauth` over the only remote connection.

## Tailnet controls

Use the Tailscale admin console to verify that the device belongs to the
intended family-only tailnet. Give support access only to the operator accounts
that need it, require the tailnet's normal account security, and remove stale
devices and members promptly. Do not paste node addresses, authorization URLs,
account names, or access-rule details into public issues or logs.

Before shipping, confirm the machine is online, key expiry has the intended
setting, Tailscale SSH and Funnel are off, it advertises no routes or exit-node
capability, client auto-update is off, and the private HTTPS dashboard works
from a second tailnet device. Recheck those controls after any membership or
policy change.

This repository does not install Tailscale access rules because the public code
must not contain private tailnet identity or policy. Review those controls in
the tailnet before shipping and after any membership change.

## On-demand support

The box sends no heartbeat or telemetry through this setup. During a support
session, connect over SSH and start with bounded checks:

```sh
tailscale status --self
messageboxctl services
messageboxctl status
systemctl --failed
df -h /
```

Read only the logs needed for the incident. Before sharing output, remove phone
numbers, WhatsApp identifiers, Wi-Fi details, NFC identifiers, recordings,
private addresses, and authentication state.

Application updates remain deliberate deployments from a reviewed commit:

```sh
git switch --detach <reviewed-commit>
./scripts/provision.sh admin@100.x.y.z
```

Record the previously installed commit and confirm there is enough disk space
before deploying. Do not combine a remote application update with an OS update
unless both changes have already passed physical testing and a rollback path is
available.

For an attended Tailscale package update:

```sh
ssh admin@100.x.y.z
sudo apt-mark unhold tailscale
sudo apt-get update
sudo apt-get install --only-upgrade tailscale
sudo apt-mark hold tailscale
tailscale version
tailscale status --self
```

Keep the SSH session open until a second connection succeeds. Apply Raspberry
Pi OS updates separately, in small batches, while a local helper is available.

## Recovery and removal

Tailscale cannot recover loss of power, failed storage, broken home internet,
or a network change that the Pi cannot join. Before shipping, make sure someone
at the household can:

- power-cycle the box;
- repeat phone-based Wi-Fi onboarding;
- connect Ethernet to the router when requested.

If remote access fails, try the local hostname or router address over Ethernet.
Do not reset application data merely to repair the network.

To remove remote support while connected locally:

```sh
sudo tailscale serve --https=443 off
sudo tailscale logout
sudo systemctl disable --now tailscaled
sudo apt-mark unhold tailscale
sudo apt-get purge tailscale
sudo rm -f /etc/apt/sources.list.d/tailscale.list
sudo rm -f /usr/share/keyrings/tailscale-archive-keyring.gpg
```

Remove `MSGBOX_TAILSCALE_HOST` from `/etc/messagebox/env` and restart the active
dashboard service if the application remains installed. Do not use
`tailscale serve reset` for this rollback because it can erase unrelated Serve
mappings.

Also delete or expire the device in the Tailscale admin console. Removing
Tailscale does not remove OpenSSH keys; review `~/.ssh/authorized_keys`
separately when transferring or retiring a box.

## Tailscale references

- [Linux installation](https://tailscale.com/docs/install/linux)
- [CLI reference](https://tailscale.com/kb/1080/cli)
- [Device key expiry](https://tailscale.com/docs/features/access-control/key-expiry)
- [Standard SSH compared with Tailscale SSH](https://tailscale.com/kb/1193/tailscale-ssh)

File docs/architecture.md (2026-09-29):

# Architecture

Button Box runs as separate systemd services with constrained users and
permissions. Runtime services use the `messagebox` account, while the web
onboarding service uses `messagebox-onboarding`. systemd limits filesystem,
device, and capability access. Wi-Fi management and reset operations retain the
root access they require.

## Runtime services

`messagebox.target` groups the enabled runtime services:

| Unit | Role |
| --- | --- |
| `messagebox-button.service` | Record, play, and send voice messages |
| `messagebox-poller.service` | Queue voice notes and ordinary video soundtracks from configured contacts |
| `messagebox-sync.service` | Keep one WhatsApp connection alive and the local store synchronized |
| `messagebox-nfc.service` | Read recipient cards and maintain NFC selection state |
| `messagebox-dash.service` | Serve the canonical household dashboard on the Wi-Fi interface |

One exact default recipient is stored with the private contact allow-list. A
recognized NFC selection has first priority for a standalone recording. With no
card and no claimed inbound message, the exact sender of the newest message
played within the last hour is preferred in both recording modes. An active
replay remains the newest played message even while the dashboard hides it in
the queue, in-flight, hold, or trash state. If that newest fresh route is invalid
or no longer allowed, recording fails closed; it never selects an older sender
or the default. The explicit default is used only when played history is absent
or expired. Unknown-card state and stale or missing NFC reader health also fail
closed before recent-sender routing.

Continuous sync owns the writable WhatsApp store. Outbound voice notes,
played reactions, and recording presence use an immediate lock attempt so the
pinned client delegates them to the active sync connection immediately.
Commands that require exclusive store access, such as recipient refresh, pause
sync and retain their bounded lock wait.

The poller accepts wacli media types `audio` and `video`, converts the first
audio track to the same mono 48 kHz WAV queue format, and retains the exact
originating chat and sender in the existing private routing sidecar. Ordinary
videos are bounded by `MSGBOX_VIDEO_MAX_BYTES` and
`MSGBOX_VIDEO_MAX_DURATION_S`. A download failure is retried; missing audio,
invalid media, or a configured-limit rejection is recorded and skipped so later
messages can continue in order. Routine service output reports only generic
processing status and elapsed time; identifiers and routing details remain in
the restricted routing sidecars and structured event log.

The pinned wacli 0.17.1 client does not expose WhatsApp circular instant video
notes. Those notes use the separate WhatsApp `ptvMessage` field, while that
release only extracts `videoMessage`; no media metadata reaches `messages list`
or `media download`. Ordinary videos are supported. Circular-note playback
therefore remains unavailable until the pinned client gains that classification
and download support, and must not be claimed from poller tests alone.

A fresh valid NFC selection reserves the next button interaction for a new
outbound message before any unread incoming message is claimed. The incoming
queue stays intact for the following ordinary press. The selection is one-shot
and expires when that recording interaction completes or is abandoned. In
hold-to-record mode, releasing before the hold threshold cancels the selected
recording intent without playing the queue or saving a silent recording.

After successful playback, the private WAV and routing sidecar move into
`queue/.played`. The dashboard shows up to 20 metadata records from the last 14
days, newest first. Playable media is further bounded to the 10 newest files and
128 MiB; a retained record whose media was pruned remains visible as
unavailable. Requeueing gives the retained item a fresh queue-order filename so
it follows messages already waiting, while its sidecar keeps the original
history identity and reply route. The sidecar is published before the WAV. A
locked history record names the actual replay file, so repeated or concurrent
requests cannot create duplicate playable entries and an interrupted
pre-publication attempt can be retried immediately. The same lock covers replay
scans, player claim/release/recovery, and dashboard hold/trash moves. Archiving
keeps the replay marker until the WAV move commits, so restart recovery cannot
lose the marker and publish a duplicate. History reads, audio access, and
requeue all enforce expiry without a polling service. Active replays remain part
of routing history even though the dashboard suppresses their duplicate Recently
played row. This covers voice notes and ordinary video soundtracks only; it does
not add circular video-note support.

## Setup services

| Unit | Role |
| --- | --- |
| `comitup.service` | Use [Comitup](https://github.com/davesteele/comitup) to manage Wi-Fi and the setup hotspot through NetworkManager |
| `comitup-web.service` | Serve the setup portal on the setup hotspot |
| `messagebox-onboarding-home.service` | Serve the portal after Wi-Fi setup |
| `messagebox-whatsapp-pairing.service` | Isolate WhatsApp pairing operations |
| `messagebox-onboarding-nfc.service` | Read tags and own private tag-first pairing state |
| `messagebox-onboarding-complete.path` | Watch for the content-free completion request |
| `messagebox-onboarding-complete.service` | Validate setup and perform the fixed runtime handoff |
| `messagebox-onboarding-voice.path` | Watch for the private fixed voice-proof request |
| `messagebox-onboarding-voice-gate.service` | Validate the request and default before activating hardware |
| `messagebox-onboarding-voice.target` | Run sync, polling, and the guided setup button without the normal runtime target |
| `messagebox-mode-reconcile.path` | Reconcile current process state after the onboarding marker changes or an interrupted transition |

Both setup portals use Gunicorn 23's `gthread` worker: one process, four request
threads and at most 64 accepted connections. Its selector waits for request
bytes before assigning a thread, so browsers' speculative empty connections
cannot occupy the application's request slots. The previous direct-to-browser
`sync` worker could wait on one empty socket and block unrelated pages and
state requests until that socket closed. Adding more sync workers only moved
that limit; it did not remove the blocking behavior.

The four request threads also let pages and state requests proceed while a
bounded Wi-Fi or pairing operation is waiting. Comitup proxy calls are
serialized inside the adapter; state and settings retain their file locks and
atomic writes. Ringtone preview uses the single process's nonblocking speaker
lock. Connectivity proof runs on state requests, not application construction,
so external network checks cannot prevent the HTML or static assets loading.
This is a private LAN/hotspot portal, not a public Internet endpoint.

## Boot-mode selection

The root-owned `/etc/messagebox-onboarding/enabled` marker is the only
persistent mode authority. At every manager start and daemon reload,
`messagebox-mode-generator` validates that marker without following links and
generates one ephemeral `multi-user.target` dependency: Comitup when the marker
contains the trusted setup value, or `messagebox.target` when the marker is
absent. An unsafe marker fails closed and selects neither mode. Neither
entrypoint is persistently enabled under `multi-user.target`.

Completion and intentional Wi-Fi reset share one transition lock. Each actor
records a transient reconciliation request before its first side effect, then
commits its mode with one atomic marker unlink or replacement. The reconciler
waits for the actor lock, reads the marker, stops the opposite entrypoint and
starts the selected entrypoint. It never deletes Wi-Fi profiles, rewrites
recipients, or repeats another transition side effect. The path watcher observes
only atomic marker creation and unlink, so unrelated onboarding configuration
writes cannot change process mode. Its `/run` request is consumed once
before convergence, so a command failure is bounded and a later actor or marker
event can request a fresh attempt.

During the voice proof, Comitup continues to own connectivity and the
setup portal while the shared sync and poller services run. The normal
`messagebox.target`, button, dashboard, and NFC services remain conflicted and
inactive.

Choosing the same default recipient is retry-safe. The private voice-proof
request is persisted before recipient setup publishes the `testing` state, so
an interrupted selection can be retried without choosing or routing to a
different recipient.

The NFC setup worker runs as `messagebox`, owns I2C and tone playback, and
offers only a group-restricted Unix socket to the isolated web portal. A read
tag UID is held privately for at most two minutes while the caregiver chooses
an opaque recipient token. Browser responses contain labels, kinds, default
state, counts, and progress only. Assignment reuses the contact store's atomic
one-tag/one-recipient transaction; tags are never written.

Skip or Done creates a fixed, content-free completion request. The root gate
validates the completed recipient state and default, enables the button, sync,
poller, canonical dashboard, and NFC reader under `messagebox.target`, removes
the setup gate, reloads the boot selector, stops
Comitup, restarts Avahi, and starts `messagebox.target`. Comitup publishes mDNS
records during setup; stopping it can remove the hostname's IPv4 record after
a collision with Avahi's own registration. Restarting Avahi after Comitup exits
republishes the local hostname for runtime. The restart must succeed before
runtime starts. A failed handoff restores the setup gate and requests Comitup
restart, preserving the completion request for retry.

`messagebox-wifi-reset.service` is a one-shot boot check for the physical Wi-Fi
reset gesture. The setup portal accesses Comitup through a restricted
D-Bus policy. NetworkManager and Avahi provide network management and local name
resolution.

WhatsApp pairing, recipient identities, message IDs, tag identifiers, and voice-proof
correlation remain behind a group-restricted Unix socket owned by the private
worker. The browser receives only opaque recipient tokens, labels, kinds, and
content-free progress booleans. Person labels are international phone numbers;
group labels use their WhatsApp names. Exact JIDs, message IDs, and tag UIDs never cross
the worker boundary.
Same-origin manual-number mutations accept a strict international number. The
private worker converts it to the exact direct-chat identity and persists it in
the same contact allow-list. A manual first choice starts the normal voice
proof, while later manual additions do not replace the default unless the user
explicitly chooses **Make default** in the completed recipient manager. The
authoritative contact-store change takes effect immediately for no-card routing;
a valid mapped NFC card still overrides it.

## Canonical dashboard and settings

Setup and runtime serve the same mobile-first HTML, CSS, and JavaScript bundle.
The bundle uses Home, Setup, Settings, Activity, and Advanced routes. Setup is a
resumable task list; successful task boundaries remain in the existing atomic
setup, recipient, voice-proof, and NFC stores. Runtime enables the same
dashboard at port 80, bound specifically to `wlan0`'s current IPv4 address.
When optional remote support is provisioned, runtime also opens the same port
on loopback for private Tailscale Serve HTTPS proxying.

Caregiver behavior is stored in `/var/lib/messagebox-settings/settings.json`.
The document is versioned, validated, revision checked, locked, and replaced
atomically. A last-good snapshot is retained. The shared
`messagebox-settings` group and setgid data directory allow the restricted
setup and runtime accounts to use the same document without widening access to
the private WhatsApp or recipient stores. The hardware loop snapshots settings
at a confirmed interaction boundary, so a browser save never interrupts active
playback, recording, or sending.

The dashboard deliberately has no login or physical confirmation. Anyone on
the household Wi-Fi, on the protected setup hotspot while setup is active, or
authorized to reach an optionally configured private tailnet origin can change
caregiver settings and play queued audio. The runtime listener binds to Wi-Fi
and, only when configured, loopback rather than every interface. The tailnet
path accepts one device-local MagicDNS hostname through the loopback proxy and
requires HTTPS same-origin mutations; Tailscale Funnel remains disabled. This
is an accepted household-device risk; do not publish port 80 through a router
or public tunnel. Browser queue operations use process-local opaque handles, so
queue filenames, raw NFC identifiers, and internal message identifiers do not
cross the browser boundary.

Wi-Fi changes cross a narrow root boundary through a private mode-0600 request
watched by `messagebox-wifi-change.path`. The root worker keeps the old
NetworkManager profile while it connects to the candidate and repeats the
association, address, route, DNS, and HTTPS proof. Only a proven candidate
replaces the old profile. A failed candidate restores and rechecks the old
profile; if that also fails, the worker reopens the protected setup hotspot.
The password is supplied to `nmcli --ask` over stdin and is never placed in a
process argument, response, status document, or log.

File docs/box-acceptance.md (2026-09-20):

# Button Box acceptance matrix

This is the canonical, reusable definition of the checks required before a box is accepted. Record each run with [the per-unit template](box-acceptance-run-template.md). Never include phone numbers, chat content, credentials, card UIDs, or recordings in a public run.

## Evidence and completion

- `TEST`: deterministic synthetic test; `UI`, `API`, and `LOG`: observed on the named live revision; `PHYSICAL`: a person operated the hardware; `ACOUSTIC`: a bounded measurement or listening check; `MOCK`: simulated hardware input.
- `Passed` applies only to the listed evidence layer. `Passed (TEST)` never proves physical behavior. Use `Blocked`, `Not run`, or `Inconclusive` honestly.
- A unit is accepted only when every Required case passes at its required layer on the same identified unit and revision, including a cold reboot. Optional NFC cases may be `Not fitted`; if NFC is fitted, all NFC cases are required.
- Run repository checks with `make check`. Run the guided device checks with `sudo -u messagebox -H /opt/messagebox/dev/hardware-test.sh`. Preserve sanitized timestamps and defect/PR links for failures.
- Validate a JSON run before delivery with `python3 scripts/dev/validate_acceptance_run.py RUN.json --expected-matrix-revision MATRIX_COMMIT`. The command rejects missing, non-passing, duplicate, insufficient-evidence, and stale revision records.

## Matrix

| ID | Required evidence | Expected result |
|---|---|---|
| BB-BUILD-01 | PHYSICAL | The recorded unit identity and final parts match the assembled box. The enclosure closes, components stay retained, cables remain intact with clearance and strain relief, and the specified power supply is used. |
| BB-HOME-01 | UI+API | Home reports Wi-Fi, WhatsApp, and runtime truthfully. |
| BB-HOME-02 | UI+LOG+ACOUSTIC | Ring control records one request and produces the selected signal. |
| BB-SETUP-01 | UI | Required and optional setup tasks render and navigate correctly. |
| BB-SETUP-02 | UI | A stale setup-only hash normalizes to the correct runtime view. |
| BB-NAV-01 | UI | Home, Setup, Settings, Activity, and Advanced hashes show matching views. |
| BB-NAV-02 | UI | Advanced WhatsApp management returns to Advanced. |
| BB-NAV-03 | UI | Advanced recipient management returns to Advanced. |
| BB-WIFI-01 | TEST | Initial scan/rescan normalizes safe access-point results. |
| BB-WIFI-02 | TEST+PHYSICAL | Failed candidate restores the working profile or safely opens setup. |
| BB-WIFI-03 | UI | Copy setup URL copies the displayed URL and reports success/failure. |
| BB-WIFI-04 | UI+API | Invalid change input is rejected without disconnecting the box. |
| BB-WA-01 | UI | Linked state is accurate and management is available. |
| BB-WA-02 | TEST+UI | Pair/start/code/copy/cancel/expiry/retry states are resumable and private. |
| BB-WA-03 | TEST+UI | Unlink requires confirmation; failure preserves account and routing. |
| BB-RECIP-01 | UI+API | Selecting the current default is idempotent and persistent. |
| BB-RECIP-02 | UI+API | The linked box account is rejected as a recipient. |
| BB-RECIP-03 | UI+API | Refresh preserves configured recipients. |
| BB-RECIP-04 | TEST+UI | Defer/resume returns to selection without state loss. |
| BB-RECIP-05 | UI+API | Re-adding an allowed recipient succeeds idempotently. |
| BB-RECIP-06 | UI+API | A malformed recipient is rejected without mutation. |
| BB-RECIP-07 | UI+API | Default can change between allowed recipients and survive reload. |
| BB-RECIP-08 | TEST | Rapid concurrent switching remains atomic and consistent. |
| BB-RECIP-09 | TEST+UI | Removing a non-default affects only that recipient. |
| BB-RECIP-10 | TEST+UI | Removing the default is rejected safely. |
| BB-RECIP-11 | TEST+UI+API | Naming or renaming a recipient preserves chat identity, default selection, and NFC mappings; names persist after reload. |
| BB-NFC-01 | UI | Waiting, back, skip, retry, and unavailable states remain coherent. |
| BB-NFC-02 | TEST+MOCK | Repeated, removed, alternating, stale, and unknown mock tags fail closed. |
| BB-NFC-03 | PHYSICAL | A real tag pairs, debounces, re-presents, reassigns, unpairs, and persists. |
| BB-NFC-04 | TEST+PHYSICAL | A fresh card selection takes priority over queued playback and recent replies in both recording modes; stale, unknown, and raced selections never route to another recipient. |
| BB-VOICE-01 | UI+LOG | One authorized voice note is received and queued once. |
| BB-VOICE-02 | ACOUSTIC | Arrival signal is distinct and matches settings/quiet hours. |
| BB-VOICE-03 | PHYSICAL | One press plays the intended queued note. |
| BB-VOICE-04 | PHYSICAL+UI | Record, stop, listen back, confirm, and send reach only the intended chat. |
| BB-VOICE-05 | TEST+PHYSICAL+LOG | Consecutive authorized messages remain in order while continuous sync stays connected during downloads and recipient refresh. |
| BB-VIDEO-01 | TEST+PHYSICAL+ACOUSTIC | An ordinary video with audio plays its soundtrack in queue order; unsupported or silent media does not block later messages. Circular video notes are not supported. |
| BB-RQ-001 | TEST+UI+PHYSICAL | Requeue retained voice and ordinary-video audio after existing messages with exact original chat labels and one replay per request. Active replays stay hidden from history until playback; restart, hold, trash, expiry, and pruning preserve identity and prevent duplicate playback. See the detailed replay sequence in [testing.md](testing.md). |
| BB-REPLY-01 | TEST+PHYSICAL+UI | In both recording modes, a standalone recording replies to the newest played chat within one hour, even if that message is requeued. An unavailable recent route blocks; expiry returns to the explicit default. NFC and queued guided replies keep their exact routes. |
| BB-AUDIO-01 | ACOUSTIC | Press acknowledgement is audible at the intended listening position. |
| BB-AUDIO-02 | UI+ACOUSTIC | Ringtone preview plays the selected sound. |
| BB-AUDIO-03 | TEST+PHYSICAL+ACOUSTIC | Startup and recording-ready cues are audible, first words are captured, and a new press interrupts the three-second send cue without being swallowed. |
| BB-SET-01 | UI+API | Unchanged save succeeds without unintended changes. |
| BB-SET-02 | UI+API | Valid change persists; original value restores; stale revision fails safely. |
| BB-ACT-01 | UI+API | Content-free counters, timeline, queue, hold, and trash render accurately. |
| BB-ACT-02 | TEST+UI | Hold/resume/trash move exactly one intended disposable message. |
| BB-ADV-01 | UI+API | Invalid listener data is rejected; valid CRUD preserves unrelated profiles. |
| BB-PERSIST-01 | UI+API | Browser reload preserves recipient, settings, and correct route. |
| BB-PERSIST-02 | API+LOG | Targeted service restart preserves state and returns healthy. |
| BB-PERSIST-03 | PHYSICAL+API+LOG | Cold reboot restores services, state, ring, and one message route. |
| BB-UPDATE-01 | TEST+API+LOG | The bounded update and rollback preserve configuration, contacts, identity, queues, permissions, and the exact prior boot selector and active services. Both setup and runtime mode migration are covered. |
| BB-TEST-01 | TEST+UI | On an explicitly enabled test rig, the report controls create, copy, and download a sanitized diagnostic bundle without exposing household data. |
| BB-LAYOUT-01 | UI | Desktop controls are visible, labeled, and usable. |
| BB-LAYOUT-02 | UI | Narrow mobile layout scrolls and exposes every active control. |
| BB-RECOVERY-01 | UI+API | API outage shows a clear error and clears it automatically after recovery. |

## Physical NFC sequence

Present a known unpaired tag; hold it to prove debounce; remove/re-present; rapidly alternate two assigned tags; present an unknown tag while idle, queued, and playing; cancel pairing before and after detection; then reassign, unpair, reboot, and verify persistence. Record latency and usable read range without recording UIDs.

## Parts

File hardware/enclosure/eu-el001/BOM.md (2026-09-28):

# EU BOM — BB-PI4-EU-001

Reference parts list for the **European EU S8 enclosure** (EL001 speaker).
Print files: [base-print.stl](exports/base-print.stl) · [lid-print.stl](exports/lid-print.stl).

Prices checked 27 Sep 2026; retailers change stock and pricing. We don't endorse any retailer.

| # | Part | Qty | Buy | Notes |
| --- | --- | --- | --- | --- |
| 1 | Raspberry Pi 4 Model B (1 GB) | 1 | [Welectron €39.90](https://www.welectron.com/Raspberry-Pi-4-B-1-GB) | Reference board at reviewed coordinates |
| 2 | 32 GB microSD card | 1 | [Conrad €14.99](https://www.conrad.de/de/p/sandisk-ultra-microsdhc-microsdhc-karte-32-gb-class-10-uhs-i-inkl-sd-adapter-2336835.html) | SanDisk Ultra A1, with adapter |
| 3 | HOTUT USB conference mic | 1 | [eBay.de €22.95](https://www.ebay.de/itm/147504383698) | Bare PCB 39 × 26 mm, 30 mm mounting pitch |
| 4 | EL-001 USB soundbar | 1 | — | Measured envelope 186 × 56 × 38 mm; USB lead included. The exact EL-001 is not currently stocked by EU retailers; the closest found ([ZETIY soundbar €35.29](https://www.ebay.de/itm/336533952004)) is 220 × 63 × 36 mm and does not fit this enclosure as designed |
| 5 | EU USB mains supply | 1 | [Welectron €7.50](https://www.welectron.com/Offizielles-Raspberry-Pi-4-Steckernetzteil-USB-C-51V-3A) | Official 15 W USB-C, EU plug (also [BerryBase €7.90](https://www.berrybase.de/offizielles-raspberry-pi-usb-c-netzteil-5-1v-3-0a-eu-schwarz)) |
| 6 | EG STARTS 100 mm illuminated arcade button, blue | 1 | [amazon.de €11.00](https://www.amazon.de/dp/B072JLSH34) | |
| 7 | Waveshare PN532 NFC HAT | 1 | — | Seated directly on the Pi. Out of stock at every EU retailer checked on 27 Sep 2026 |
| 8 | Full-size NFC cards | — | [nfc-tag-shop.de €1.69/pc from 10](https://www.nfc-tag-shop.de/NFC-Karte-PVC-85-6-x-54-mm-NTAG213-180-Byte-orange-matt/17068) | NTAG213, credit-card format; 3+ intended age |
| 9 | Enclosure lid (EU R4, 3D-printed) | 1 | Print it | [lid-print.stl](exports/lid-print.stl) |
| 10 | Enclosure base (EU R4, 3D-printed) | 1 | Print it | [base-print.stl](exports/base-print.stl) |
| 11 | Mounting fasteners | — | [Conrad €16.95](https://www.conrad.de/de/p/thicon-models-20139-schraubensortiment-300-st-2898917.html) | M3 screw/nut/washer assortment, 300 pc |
| 12 | Internal wiring / connectors | — | — | Match terminal sizes on your button before ordering |
| 13 | PLA feedstock | — | [3DJake $18.05/kg](https://www.3djake.com/esun/pla-black-7?sai=11751) | eSUN PLA+, 1.75 mm |

Slice the two `*-print` STLs in millimeters; the base floor and lid roof lie on Z=0.
See [eu-el001/README.md](README.md) for CAD source, rebuild instructions and review notes.

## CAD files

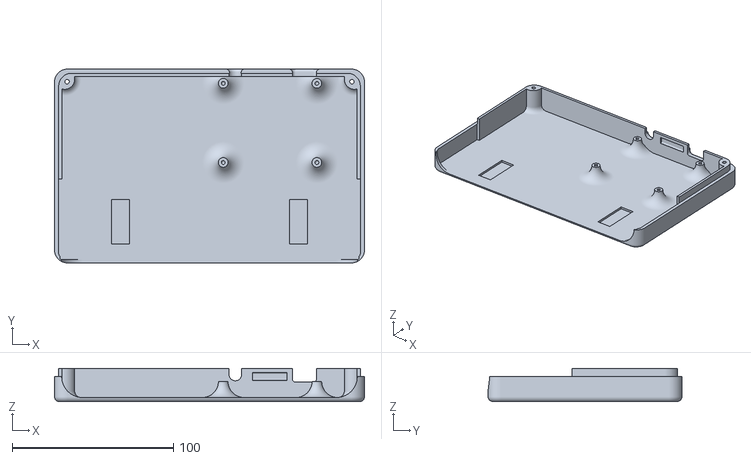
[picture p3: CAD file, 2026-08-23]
hardware/enclosure/button-box-enclosure-bottom.stl
192.0 x 120.0 x 20.5

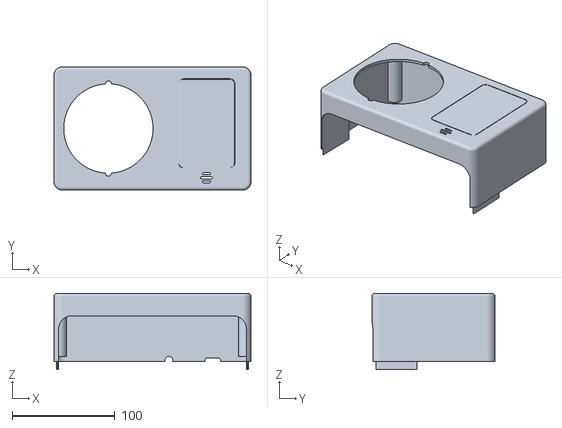
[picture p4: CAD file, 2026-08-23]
hardware/enclosure/button-box-enclosure-top.stl
192.0 x 120.0 x 74.5

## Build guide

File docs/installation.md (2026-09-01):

# Installation

Validate installation changes on a spare Raspberry Pi 4 and microSD card. Do
not overwrite a working device without a tested backup.

## Manufacturer preparation

1. In Raspberry Pi Imager, install Raspberry Pi OS Lite 64-bit based on Debian
   13. Enable SSH and create a non-root sudo-capable administrator. Set the
   hostname to the box's zero-padded number, such as `button-box-001`, and use
   the same number on the physical label and in inventory.
2. Review the included licensed guided-reply prompt set described in
   [`sounds/README.md`](../sounds/README.md). These recordings are required for
   the two-way voice proof.
3. From a repository clone on another computer, provision over SSH:

   ```sh
   ./scripts/provision.sh admin@button-box-NNN.local
   ```

   This transfers the installer's explicit source allowlist and runs setup on
   the Pi. The installer validates every prompt before making system changes.
   To use an alternate licensed prompt set, pass its directory with
   `--guided-prompts DIR`. Alternatively, clone the repository onto the Pi and
   run `./scripts/setup.sh` there as a non-root sudo-capable administrator.
   Neither method transfers device runtime state, pairs WhatsApp, or starts
   Button Box services.

   Connect the microphone and USB speaker before running setup. On a fresh
   installation, setup selects the lowest-numbered ALSA capture device and USB
   playback device, then records their card names in `/etc/messagebox/env`;
   setup fails if either is unavailable. Later updates preserve the existing
   file and operator customization.

   The Pi needs internet access during setup. See
   [Internet access for a fresh card](developer-onboarding.md#internet-access-for-a-fresh-card).
   For an optionally shipped box that needs private, consented remote
   maintenance, complete the [Tailscale remote-support procedure](remote-support.md)
   while LAN access is still available. Tailscale is independent of the Button
   Box application install and does not replace ordinary OpenSSH keys.
4. Configure protected Wi-Fi onboarding with
   `sudo messagebox-init-wifi-onboarding`.
5. Print the displayed box number, hotspot name, password, and setup URL for the
   matching box. Treat the hotspot password as a credential: do not commit it,
   put it in shared logs, or retain an unprotected digital copy.
6. Run `sudo messageboxctl reset-wifi`. Verify the hotspot if needed, then run
   `sudo shutdown now` and package the printed insert with the powered-down box.
   Do not complete browser onboarding during manufacturing.

## Recipient setup

1. Power on Button Box.
2. Join its setup hotspot with the supplied password and open the printed URL.
3. Submit the home Wi-Fi credentials. The setup hotspot will disappear.
4. Reconnect the phone to home Wi-Fi and reopen the same URL, such as
   `http://button-box-001.local/`. The network switch may take up to two
   minutes; retry if the page is not ready.
5. Pair WhatsApp using a number beginning with `+` and its international country
   code.
6. Choose a recent WhatsApp person or group as the initial default recipient, or
   enter a person's international phone number beginning with `+`. On a clean
   account, the selected person or group must still send the linked number a
   new message before the voice proof. Choosing **Do this later** pauses setup
   and leaves messaging and NFC disabled.
7. Ask the selected recipient to send a new voice note. Press the Button Box button to
   hear it, record the prompted reply, review it, and press again to approve the
   send. Messages received before selection are deliberately excluded.
8. After the two-way proof, optionally allow-list more recent people or groups
   in the recipient manager, or enter another international phone number
   manually. You can switch the default among allowed recipients in the manager;
   removing a recipient also removes that recipient's tag mappings.
9. Select **Continue to NFC setup**. Hold a tag over the reader until Button Box
   beeps, remove it, and choose the person or group it should represent. Pair as
   many tags as needed; multiple tags may point to one recipient.
10. An already-paired tag shows its current recipient and requires an explicit
    **Reassign** before it can move. The flow reads tag identifiers but never
    writes data to a tag.
11. Choose **Skip NFC setup** before the first tag or **Done** after pairing.
    Either action completes setup and activates messaging. If no tags are
    mapped, the default recipient works without the NFC reader.

The manufacturer must not complete these steps for the recipient.

After setup, the same printed URL opens the canonical Button Box dashboard.
Home shows connection and runtime health; Setup preserves the completed task
list; Settings controls button behavior, message length, ringtone, volume,
arrival signal, quiet hours, time zone, and the NFC confirmation beep. Activity
contains the privacy-sensitive timeline, browser audio, and queue controls.
Advanced contains concise health and listener-profile information.

The dashboard intentionally has no login. Anyone on household Wi-Fi can change
settings and play queued audio. Do not forward port 80 or publish the dashboard
through a tunnel. Runtime binds only to the Wi-Fi interface.

If the reader is unavailable, Retry or skip NFC setup. Once any tag is mapped,
runtime routing remains fail-closed when the NFC reader is unhealthy; it never
guesses the default while mapped-card state is unsafe. Do not continue with
`messagebox-dev-onboard`; it remains an independent prototype workflow.

Before deployment, run the [physical test scenarios](testing.md#physical-test-scenarios)
on a spare device.

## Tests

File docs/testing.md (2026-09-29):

# Testing

## Repository tests

- `make test` runs the synthetic Python, loopback HTTP, and JavaScript UI-contract
  suites. `uv` provides Gunicorn 23.0.0, matching the pinned device package.
  Dependencies may download on first use; the tests themselves use no external
  network, credentials or hardware.
- `make lint` requires `uvx` (from `uv`) and `bunx` (from Bun). It runs Ruff for
  Python, ShellCheck for shell scripts, and Biome for frontend assets. `uvx` and
  `bunx` download these tools on first use.
- `make check` runs syntax checks, linting, and tests.

No project virtual environment or repository-local dependency installation is
required.

Synthetic tests cover routing, onboarding, redaction, pairing, NFC, and recovery
contracts. They do not replace physical Pi, phone, network, or hardware tests.

## Regression test matrix

Matrix case IDs are permanent. Add new cases with a new descriptive ID; do not
renumber or reuse an existing ID.

Every confirmed product bug must add a matrix case or explicitly update an
existing case and its regression test before the fix is complete. If automation
is impossible, record the reason in the pull request and keep a precise manual
assertion in this matrix.

| Case ID | Regression | Synthetic setup and expected result | Software evidence | Separate physical assertion |
| --- | --- | --- | --- | --- |
| `BB-WEB-001` | Idle browser connections or a slow operation freeze setup | Launch both portal service commands with the pinned server and a synthetic app. Hold six empty TCP connections open; pages, static assets and state must still respond within one second. Hold a separate operation open and repeat, then release it. HTML/static loading must not run connectivity checks. | `tests/test_onboarding_http.py::OnboardingHTTPTests`, `tests/test_onboarding_api.py::OnboardingAPITests::test_home_page_loads_before_state_request_proves_connectivity`, and the shared-proxy serialization test in `tests/test_comitup_adapter.py` | On the exact installed revision, navigate Home, Setup, Connect Wi-Fi and Link WhatsApp in a real phone browser on both home Wi-Fi and the hotspot. Verify that tabs and links respond promptly while a scan runs. Record HTTP timing separately from the person's observed touch result. |
| `BB-RX-001` | Consecutive inbound voice notes | Provide two allowed audio messages from different synthetic senders in one poll while sync remains active. Both queue exactly once in oldest-first order with unique queue filenames; media retrieval is read-only and does not make continuous sync release the store lock. | `tests/test_voicepoll.py::PollingStoreTests::test_consecutive_senders_queue_oldest_first_without_store_write_lock` and `tests/test_whatsapp_pairing.py::WhatsAppFrontendAndServiceContractTests::test_service_separates_web_user_from_live_store_and_keeps_runtime_stopped` | On a test box, send two voice notes from separate test accounts in quick succession while the first is downloading. Verify both appear and play once in send order. Record device, revision, observed times, and result without storing message content or account identifiers. |
| `BB-RQ-001` | Caregiver requeues recently played media | Archive synthetic voice audio and an ordinary video soundtrack after playback. The dashboard returns safe newest-first metadata and an opaque handle. Each replay appends after existing waiting messages using a fresh queue identity while preserving its original history identity, exact sender/chat display identity, and routing sidecar. An active replay is absent from Recently played until it is played again, including while held or in trash. Repeated and concurrent requests create one playable WAV; claim, release, recovery, hold, trash, and replay scans observe complete transitions. Restart preserves real queued state, while interrupted publication or archive commits recover without a phantom duplicate. Expired, missing or policy-pruned media cannot stream or requeue. | `tests/test_played_history.py::PlayedHistoryTests`, `tests/test_dashboard_queue_hold.py::DashboardQueueHoldTests::test_recently_played_is_newest_first_safe_and_requeues_once`, `tests/test_dashboard_queue_hold.py::DashboardQueueHoldTests::test_dashboard_move_waits_for_replay_history_transition`, and the recently-played cases in `tests/onboarding-ui.test.js` | On a test box at the exact candidate revision, leave two synthetic messages waiting, then requeue a retained voice note and ordinary video soundtrack. Confirm both append in request order with the original sender/chat labels and disappear from Recently played while queued, held or in trash. Refresh and restart before playback, then verify exactly one playback each, that each returns to Recently played only after playback, and that reply routing remains bound to the original chats. Confirm a deliberately expired or pruned fixture cannot stream or requeue. Do not treat circular video notes as supported. |
| `BB-RT-001` | Recent-sender routing cannot drift during replay or bypass NFC | Archive an older message from sender A and a newer message from sender B. Requeue B and move it through queue, in-flight, hold, and trash; B remains the recent route even while hidden from Recently played. A removed or invalid fresh B route blocks instead of choosing A or the default. With no card or claimed inbound, standalone hold-release and tap-review sessions use fresh B; a fresh card still wins, and unknown-card or unhealthy-reader state blocks. No/expired history alone permits the configured default. | `tests/test_played_history.py::PlayedHistoryTests::test_active_newest_replay_remains_the_recent_route_in_every_queue_state`, `tests/test_played_history.py::PlayedHistoryTests::test_invalid_or_removed_newest_route_never_selects_an_older_sender`, and the recent-routing cases in `tests/test_button_routing.py` | On the exact candidate revision, play messages from two test chats, requeue the newer one, and exercise both recording modes. Verify replies stay bound to the newer chat through refresh/restart/hold/trash, a fresh NFC choice overrides it, and removed-contact, unknown-card, and unavailable-reader states block without sending to an older/default chat. |

## Physical test scenarios

Use a spare Raspberry Pi 4 with a freshly imaged test microSD card. Confirm it
did not inherit state from a development or household device.

For installation and consumer onboarding, test:

- Clean installation and manufacturer handoff
- Wi-Fi success, failure, and recovery
- WhatsApp pairing and interruption
- Empty-account recipient discovery and manual refresh
- Manual international-number selection and allow-listing, including invalid
  formats, duplicates, and default preservation when merely adding a recipient
- People displayed by valid international phone number, invalid direct-chat
  placeholders excluded, and refresh after the 100-message pairing bootstrap
  cap has been reached
- Initial default selection, switching the default among allowed recipients,
  protection from removing the current default, no-card routing after a switch,
  defer/resume, and recipient-manager recovery
- New voice note and ordinary video with speech, physical playback, guided reply
  review, and accepted send. Confirm a no-audio video is skipped and the next
  valid message still plays. Circular instant video notes remain an explicit
  unsupported case with the pinned wacli 0.17.1 client.
- Zero-tag Skip, person and group pairing, multiple tags per recipient,
  explicit reassignment, remove-after-beep behavior, Retry/Skip when the reader
  is unavailable, and the distinct read/success tones
- Reload within and after the two-minute pending-tag window, completion with and
  without mappings, and the onboarding-to-runtime service handoff
- After both Skip and Done, verify from another device on the same Wi-Fi that
  the printed `.local` hostname resolves to the box's current Wi-Fi IPv4 address
  and that the dashboard opens. Repeat after the advertised mDNS records expire
  from client caches and after a cold reboot. A listening port or a successful
  request made on the box itself is insufficient for this check.
- Reboot and power loss during onboarding transitions

For the standalone developer flow and runtime, test:

- Explicit-default and multiple-recipient routing
- NFC enrollment, removal, and unknown cards
- Microphone, speaker, LED, and button behavior
- First send and reply
- Reboot and power-loss recovery
- Rollback to the previous working release

# Recipient and activity checks during setup

Navigation refetches server state, including after the setup-to-runtime handoff.
Runtime needing attention must not be labeled "Setup in progress". Verify Home
and Activity after completion without reloading the tab.

After scanning an unpaired tag, allow a new international number directly on
"Who is this tag for?". The scan and existing mappings remain intact; adding
does not change the default or assign the tag. Choose the new recipient to
assign explicitly. Check invalid/self numbers, retry after an uncertain response,
and background polling while typing. Existing allowed-recipient validation applies.

Activity is read-only during setup and shows content-free recorded events or
an empty state. It uses the existing group-restricted pairing-worker socket:
the portal does not gain runtime-store access. Test before WhatsApp linking,
after receive/play/send events, with no history, and with the worker unavailable.
Never complete setup or expose audio/recipient identifiers just to view events.

# Early send during own-recording review

In tap/review mode, a fresh deliberate press during review of the user's own
recording stops preview and approves that recording once. It skips the later
send prompt, approval timeout and delete warning. Incoming-message listening
is unchanged. A held recording-stop press must be released before review can
accept a new press. With no review press, the existing prompt, timeout, warning
and cancellation flow remains unchanged. Approval queues a send; only actual
send success may trigger the successful-send sound.

On a named box, verify early review approval for both standalone and reply
flows, a held recording-stop press, a short bounce, no approval/cancellation,
and exactly one outgoing voice note in the intended chat. Keep software tests
and physical switch/audio/delivery evidence separate.

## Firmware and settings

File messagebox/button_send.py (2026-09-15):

#!/usr/bin/env python3
"""Button Box physical-button service with caregiver-selectable interaction."""

import json
import os
import queue
import select
import signal
import subprocess
import sys
import threading
import time
import uuid
from datetime import datetime
from pathlib import Path
from zoneinfo import ZoneInfo

from gpiozero import Button, LED

from messagebox.guided_reply import (
    EnergyVAD,
    GuidedSession,
    OutboxStore,
    RecordingResult,
    claim_inbox_file,
    discard_held_playback_press,
    finish_inbox_file,
    invalid_prompt_files,
    raw_pcm_to_trimmed_wav,
    recover_inflight_files,
    release_inbox_file,
    should_ring_after_unsent_session,
    voice_send_command,
)
from messagebox.listened_receipts import AnnouncementGate, ReceiptStore, parse_wacli_send_id
from messagebox.contacts import ContactError, ContactStore
from messagebox.nfc_state import AnnouncementStore, NfcError, active_selection, claim_selection
from messagebox.runtime_paths import APP_DIR, OUTBOX_DIR as DEFAULT_OUTBOX_DIR
from messagebox.runtime_paths import QUEUE_DIR as DEFAULT_QUEUE_DIR
from messagebox.runtime_paths import (
    CONTACTS_FILE,
    NFC_ANNOUNCEMENT_FILE,
    NFC_HEALTH_FILE,
    NFC_SELECTION_FILE,
    RUNTIME_DIR,
    STATE_DIR as DEFAULT_STATE_DIR,
)
from messagebox.settings import SettingsReader, ringtone_path


MIC_DEV = os.environ.get("MSGBOX_MIC_DEV", "plughw:CARD=Device,DEV=0")
SPK_DEV = os.environ.get("MSGBOX_SPK_DEV", "plughw:CARD=Device_1,DEV=0")
SPEAKER_CARD = os.environ.get("MSGBOX_SPEAKER_CARD", "Device")
SPEAKER_CONTROL = os.environ.get("MSGBOX_SPEAKER_CONTROL", "PCM")
BUTTON_PIN = int(os.environ.get("MSGBOX_BUTTON_PIN", "17"))
LED_PIN = int(os.environ.get("MSGBOX_LED_PIN", "26"))
LOCK_WAIT = os.environ.get("MSGBOX_LOCK_WAIT", "60s")
WACLI_BIN = "/usr/local/bin/wacli"
QUEUE_DIR = str(DEFAULT_QUEUE_DIR)
OUTBOX_DIR = str(DEFAULT_OUTBOX_DIR)
STATE_DIR = str(DEFAULT_STATE_DIR)
TEMP_DIR = os.path.join(str(RUNTIME_DIR), "guided-reply-tmp")
EVENTS_FILE = os.path.join(STATE_DIR, "events.jsonl")
LISTENED_DIR = os.path.join(STATE_DIR, "listened-receipts")
LISTENED_FALLBACK_WAV = os.environ.get(
    "MSGBOX_LISTENED_FALLBACK_WAV",
    str(APP_DIR / "sounds" / "listen-receipts" / "someone-listened.wav"),
)
SEND_SUCCESS_WAV = str(APP_DIR / "sounds" / "feedback" / "sent-swoosh.wav")
send_success_notices = queue.SimpleQueue()

LISTENED_POLL_S = float(os.environ.get("MSGBOX_LISTENED_POLL_S", "0.2"))
LISTENED_RETRY_S = float(os.environ.get("MSGBOX_LISTENED_RETRY_S", "30"))
RING_REQUEST_FILE = str(RUNTIME_DIR / "ring-request")
NFC_SELECTION_TTL_S = float(os.environ.get("MSGBOX_NFC_SELECTION_TTL_S", "30"))
NFC_ANNOUNCEMENT_POLL_S = float(
    os.environ.get("MSGBOX_NFC_ANNOUNCEMENT_POLL_S", "0.1")
)
NFC_HEALTH_MAX_AGE_S = float(os.environ.get("MSGBOX_NFC_HEALTH_MAX_AGE_S", "5"))
PLACE_TOKEN_WAV = os.environ.get(
    "MSGBOX_PLACE_TOKEN_WAV",
    str(APP_DIR / "sounds" / "nfc" / "place-token.wav"),
)
GUIDED_SILENCE_SECONDS = float(os.environ.get("MSGBOX_GUIDED_SILENCE_SECONDS", "20"))
PROMPT_DIR = Path(
    os.environ.get(
        "MSGBOX_PROMPT_DIR",
        str(APP_DIR / "sounds" / "guided-reply"),
    )
)
PROMPTS = {
    "reply": PROMPT_DIR / "reply-countdown.wav",
    "standalone": PROMPT_DIR / "standalone-countdown.wav",
    "send": PROMPT_DIR / "press-to-send.wav",
    "delete_warning": PROMPT_DIR / "delete-warning.wav",
    "not_sent": PROMPT_DIR / "not-sent.wav",
}

# Quiet hours: lamp dark, no ringtone (messages still queue; a deliberate press
# still plays). Overnight arrivals do not ring when quiet hours end.
RING_PHRASE = [
    (True, 1.2),
    (True, 1.6),
    (False, 0.4),
    (True, 1.2),
    (True, 1.6),
    (False, 0.6),
] * 3
MIN_HOLD_S = 0.7
POLL_S = 0.005
SETTLE_OPEN_S = 0.5
CONFIRM_PRESS_S = 0.08
CONFIRM_RELEASE_S = 0.2
LED_REFRESH_S = 0.5
SEND_FAIL_BEEP_AT = 3
BEEPS = {
    # The press acknowledgement must survive room noise and the start of the
    # following prompt. The old 70 ms tone at ffmpeg's default level was not
    # audible in a real-box acoustic test.
    "press": (str(RUNTIME_DIR / "beep-press.wav"), "880", "0.40", "12"),
    "nfc": (str(RUNTIME_DIR / "beep-nfc.wav"), "880", "0.40", "12"),
    "start": (str(RUNTIME_DIR / "beep-start.wav"), "880", "0.12", "0"),
    "fail": (str(RUNTIME_DIR / "beep-fail.wav"), "220", "0.6", "0"),
}


def log(msg):
    print(f"{time.strftime('%H:%M:%S')} {msg}", flush=True)


def log_event(event_type, **fields):
    """Append content-free operational events; audio is never inspected/logged."""
    try:
        fields["type"] = event_type
        fields["ts"] = time.time()
        os.makedirs(os.path.dirname(EVENTS_FILE), exist_ok=True)
        with open(EVENTS_FILE, "a", encoding="utf-8") as handle:
            handle.write(json.dumps(fields, sort_keys=True) + "\n")
    except Exception as exc:
        log(f"event log error: {exc}")


def quiet_hours(settings=None, now=None):
    settings = settings or caregiver_settings()
    quiet = settings["quiet_hours"]
    if not quiet["enabled"]:
        return False
    current = now or datetime.now(ZoneInfo(settings["timezone"]))
    minute = current.hour * 60 + current.minute
    start_hour, start_minute = (int(value) for value in quiet["start"].split(":"))
    end_hour, end_minute = (int(value) for value in quiet["end"].split(":"))
    start = start_hour * 60 + start_minute
    end = end_hour * 60 + end_minute
    if start == end:
        return True
    if start < end:
        return start <= minute < end
    return minute >= start or minute < end


_applied_volume_revision = None


def apply_master_volume(settings=None):
    global _applied_volume_revision
    settings = settings or caregiver_settings()
    if settings["revision"] == _applied_volume_revision:
        return True
    result = subprocess.run(
        [
            "amixer",
            "-q",
            "-c",
            SPEAKER_CARD,
            "sset",
            SPEAKER_CONTROL,
            f'{settings["master_volume_percent"]}%',
            "unmute",
        ],
        check=False,
    )
    if result.returncode == 0:
        _applied_volume_revision = settings["revision"]
        return True
    return False


def make_beeps():
    for path, frequency, duration, gain_db in BEEPS.values():
        # These files are generated assets, so rewrite them at startup. Keeping
        # an existing file would silently retain an older duration or gain after
        # a software update.
        subprocess.run(
            [
                "ffmpeg",
                "-loglevel",
                "error",
                "-y",
                "-f",
                "lavfi",
                "-i",
                f"sine=frequency={frequency}:duration={duration}",
                "-filter:a",
                f"volume={gain_db}dB",
                path,
            ],
            check=True,
        )


def beep(name):
    subprocess.run(["aplay", "-q", "-D", SPK_DEV, BEEPS[name][0]])


def acknowledge_guided_press(action, session_id=None):
    """Give immediate, content-free feedback for each actionable press."""
    beep("press")
    fields = {"action": action}
    if session_id:
        fields["session_id"] = session_id
    log_event("guided_press", **fields)


def queued():
    try:
        return sorted(name for name in os.listdir(QUEUE_DIR) if name.endswith(".wav"))
    except FileNotFoundError:
        return []


def legacy_outbox_files():
    try:
        return sorted(name for name in os.listdir(OUTBOX_DIR) if name.endswith(".wav"))
    except FileNotFoundError:
        return []


_recording = False
_guided_active = False
outbox_store = None
receipt_store = None
announcement_gate = AnnouncementGate(LISTENED_POLL_S, LISTENED_RETRY_S)
nfc_announcement_store = AnnouncementStore(NFC_ANNOUNCEMENT_FILE)
_last_nfc_announcement_poll = 0.0
settings_reader = SettingsReader()


def caregiver_settings():
    return settings_reader.snapshot()


def current_recipient_context(*, claim=False):
    """Resolve standalone routing from an authoritative contacts snapshot."""
    try:
        document = ContactStore(CONTACTS_FILE).load()
        contacts = document["contacts"]
        has_cards = any(contact["card_uids"] for contact in contacts.values())
        if has_cards:
            try:
                if time.time() - os.stat(NFC_HEALTH_FILE).st_mtime > NFC_HEALTH_MAX_AGE_S:
                    log("recipient unavailable: NFC reader health is stale")
                    return None
            except OSError:
                log("recipient unavailable: NFC reader health is unavailable")
                return None
            resolver = claim_selection if claim else active_selection
            selection_existed = Path(NFC_SELECTION_FILE).exists()
            context = resolver(
                CONTACTS_FILE,
                NFC_SELECTION_FILE,
                max_age=NFC_SELECTION_TTL_S,
            )
            if context is not None:
                return {
                    "contact": context["contact"],
                    "uid": context["uid"],
                    "via_card": True,
                }
            if selection_existed:
                log("recipient unavailable: stale card selection")
                return None
            if nfc_announcement_store.pending_action() in {"unknown", "invalid"}:
                log("recipient unavailable: unrecognized card presentation")
                return None
        default_recipient = document["default_recipient"]
        if default_recipient is None:
            log("recipient unavailable: no default configured")
            return None
        contact = contacts.get(default_recipient)
        if contact is None:
            log("recipient unavailable: default is invalid")
            return None
        return {
            "contact": {"jid": default_recipient, **contact},
            "via_card": False,
        }
    except (ContactError, NfcError, OSError) as exc:
        log(f"contact routing unavailable: {exc}")
        return None


def routing_mode():
    """Describe startup routing without exposing a contact JID."""
    try:
        document = ContactStore(CONTACTS_FILE).load()
    except (ContactError, OSError) as exc:
        log(f"contact routing unavailable: {exc}")
        return "unavailable"
    if not document["contacts"]:
        return "no_contacts"
    if document["default_recipient"] is None:
        return "no_default"
    return "default_recipient"


def wait_for_hold_intent(
    is_pressed,
    minimum_hold_s,
    poll_s,
    *,
    monotonic=time.monotonic,
    sleeper=time.sleep,
):
    """Classify the shared button before resolving or claiming a recipient."""
    if minimum_hold_s <= 0 or poll_s <= 0:
        raise ValueError("button timing values must be positive")
    started = monotonic()
    while monotonic() - started < minimum_hold_s:
        if not is_pressed():
            return "play"
        sleeper(poll_s)
    return "record"


def prompt_for_token():
    """Refuse outbound recording without leaking the previous selection."""
    log_event("nfc_token_required")
    if os.path.isfile(PLACE_TOKEN_WAV):
        subprocess.run(["aplay", "-q", "-D", SPK_DEV, PLACE_TOKEN_WAV], check=False)
    else:
        log(f"place-token prompt missing: {PLACE_TOKEN_WAV}")
        beep("fail")


def block_unavailable_recipient():
    """Give safe feedback without treating an unconfigured box as card-ready."""
    mode = routing_mode()
    log_event("recipient_required", routing_mode=mode)
    if mode in {"card_selection", "default_recipient"}:
        if play_pending_nfc_announcement(force=True) != "unknown":
            if mode == "card_selection":
                prompt_for_token()
            else:
                beep("fail")
    else:
        beep("fail")


def _play_nfc_prompt(uid, action, card_clip):
    beeped = False
    if caregiver_settings()["nfc_confirmation_beep"]:
        beep("nfc")
        beeped = True
    card_clip = os.path.expanduser(card_clip)
    if card_clip and os.path.isfile(card_clip):
        played = subprocess.run(
            ["aplay", "-q", "-D", SPK_DEV, card_clip], check=False
        ).returncode == 0
        mode = "spoken"
    elif beeped and action in ("recognized", "selected", "enrolled"):
        played = True
        mode = "beep"
    else:
        played = False
        mode = "missing"
        log(f"NFC announcement clip missing: {card_clip or '(not configured)'}")
    log_event("nfc_announced", action=action, played=played, mode=mode)
    if played:
        nfc_announcement_store.acknowledge(uid)
    else:
        nfc_announcement_store.clear_acknowledgement()
        beep("fail")
    return played


def play_pending_nfc_announcement(*, force=False, expected_uid=None):
    """Play at most one reader request while this process exclusively owns audio."""
    global _last_nfc_announcement_poll
    now = time.monotonic()
    if not force and now - _last_nfc_announcement_poll < NFC_ANNOUNCEMENT_POLL_S:
        return False
    _last_nfc_announcement_poll = now
    request = nfc_announcement_store.take()
    if request is None:
        return None
    if expected_uid is not None and request["uid"] != expected_uid:
        return None
    return request["action"] if _play_nfc_prompt(
        request["uid"], request["action"], request["prompt"]
    ) else None


def ensure_nfc_confirmation(context):
    """Require successful feedback for this selected tag."""
    uid = context.get("uid")
    if uid is None or nfc_announcement_store.is_acknowledged(uid):
        return True
    if play_pending_nfc_announcement(force=True, expected_uid=uid):
        return True
    contact = context["contact"]
    return _play_nfc_prompt(uid, "selected", contact.get("card_clip", ""))


def legacy_job_recipient(path):
    """Use only the recipient snapshot bound at recording time."""
    try:
        with open(path + ".json", encoding="utf-8") as handle:
            recipient = json.load(handle).get("recipient")
        if (
            isinstance(recipient, str)
            and recipient
            and recipient.strip() == recipient
            and "@" in recipient
            and not any(character.isspace() for character in recipient)
        ):
            return recipient
    except (OSError, AttributeError, ValueError, json.JSONDecodeError):
        pass
    return None


def bind_legacy_job_recipient(path, recipient):
    """Persist routing before the WAV becomes visible to the sender thread."""
    metadata_path = path + ".json"
    temporary_path = metadata_path + ".part"
    with open(temporary_path, "w", encoding="utf-8") as handle:
        json.dump({"version": 1, "recipient": recipient}, handle, sort_keys=True)
        handle.flush()
        os.fsync(handle.fileno())
    os.replace(temporary_path, metadata_path)


def track_sent_for_receipts(sent, recipient, *, local_message_id, flow):
    """Persist the WhatsApp ID after acceptance without risking a duplicate send."""
    whatsapp_id = parse_wacli_send_id(sent.stdout)
    if not whatsapp_id:
        log_event(
            "listen_tracking_unavailable",
            message_id=local_message_id,
            flow=flow,
            reason="missing_wacli_id",
        )
        return None
    try:
        tracked = receipt_store.track_sent(
            whatsapp_id,
            recipient,
            local_message_id=local_message_id,
            flow=flow,
        )
    except Exception as exc:
        tracked = False
        log(f"receipt tracking error after accepted send: {type(exc).__name__}")
    if not tracked:
        log_event(
            "listen_tracking_unavailable",
            message_id=local_message_id,
            flow=flow,
            reason="persist_failed",
        )
        return None
    return whatsapp_id


def send_legacy_outbox_file(fname):
    """Keep pre-feature durable WAV jobs working with the family-group target."""
    path = os.path.join(OUTBOX_DIR, fname)
    metadata_path = path + ".json"
    recipient = legacy_job_recipient(path)
    if not recipient:
        log(f"legacy send blocked for {fname}: no bound recipient")
        log_event("send_blocked", flow="legacy", reason="missing_recipient")
        return False
    ogg = os.path.join(TEMP_DIR, f"legacy-{uuid.uuid4().hex}.ogg")
    duration = wait_s = None
    try:
        milliseconds, _, raw_duration = fname[:-4].partition("-")
        wait_s = round(time.time() - int(milliseconds) / 1000, 1)
        duration = float(raw_duration)
    except ValueError:
        pass
    converted = subprocess.run(
        [
            "ffmpeg",
            "-loglevel",
            "error",
            "-y",
            "-i",
            path,
            "-c:a",
            "libopus",
            "-b:a",
            "32k",
            "-ar",
            "48000",
            "-ac",
            "1",
            ogg,
        ]
    )
    if converted.returncode != 0:
        try:
            os.remove(ogg)
        except OSError:
            pass
        bad = os.path.join(OUTBOX_DIR, ".bad")
        os.makedirs(bad, exist_ok=True)
        os.rename(path, os.path.join(bad, fname))
        if os.path.exists(metadata_path):
            os.replace(metadata_path, os.path.join(bad, fname + ".json"))
        log(f"ffmpeg failed on legacy {fname} - moved to .bad")
        log_event("send_failed", flow="legacy", reason="convert")
        return True
    sent = subprocess.run(
        [
            WACLI_BIN,
            "send",
            "voice",
            "--file",
            ogg,
            "--to",
            recipient,
            "--lock-wait",
            LOCK_WAIT,
            "--json",
        ],
        capture_output=True,
        text=True,
    )
    try:
        os.remove(ogg)
    except OSError:
        pass
    if sent.returncode == 0:
        whatsapp_id = track_sent_for_receipts(
            sent,
            recipient,
            local_message_id=fname,
            flow="legacy",
        )
        os.remove(path)
        try:
            os.remove(metadata_path)
        except FileNotFoundError:
            pass
        send_success_notices.put(time.monotonic())
        log(f"SENT legacy {fname} (queued {wait_s}s)")
        log_event(
            "sent",
            flow="legacy",
            target=recipient,
            dur=duration,
            queue_wait_s=wait_s,
            whatsapp_id=whatsapp_id,
        )
        return True
    log(f"legacy send failed for {fname}: {(sent.stderr or sent.stdout).strip()[:200]}")
    return False


def send_guided_job(job):
    """Send only to the recipient stored atomically with this approved audio."""
    ogg = os.path.join(TEMP_DIR, f"guided-{uuid.uuid4().hex}.ogg")
    converted = subprocess.run(
        [
            "ffmpeg",
            "-loglevel",
            "error",
            "-y",
            "-i",
            str(job.audio_path),
            "-c:a",
            "libopus",
            "-b:a",
            "32k",
            "-ar",
            "48000",
            "-ac",
            "1",
            ogg,
        ]
    )
    if converted.returncode != 0:
        try:
            os.remove(ogg)
        except OSError:
            pass
        outbox_store.set_state(job, "failed", increment_attempts=True)
        log_event("outbox_failed", message_id=job.message_id, reason="convert")
        log(f"guided conversion failed {job.message_id}; retained for parent")
        return True

    # Persist 'sending' before crossing the external side-effect boundary.  A
    # crash from here until completion becomes uncertain on restart, never an
    # automatic duplicate resend.
    job = outbox_store.set_state(job, "sending", increment_attempts=True)
    sent = subprocess.run(
        voice_send_command(WACLI_BIN, ogg, job.recipient, LOCK_WAIT),
        capture_output=True,
        text=True,
    )
    try:
        os.remove(ogg)
    except OSError:
        pass
    if sent.returncode == 0:
        whatsapp_id = track_sent_for_receipts(
            sent,
            job.recipient,
            local_message_id=job.message_id,
            flow=job.flow_kind,
        )
        outbox_store.complete(job)
        send_success_notices.put(time.monotonic())
        log_event(
            "sent",
            flow=job.flow_kind,
            message_id=job.message_id,
            target=job.recipient,
            dur=job.duration,
            whatsapp_id=whatsapp_id,
        )
        log(f"SENT guided {job.message_id}")
        return True
    outbox_store.set_state(job, "pending")
    log_event("outbox_retry", message_id=job.message_id, flow=job.flow_kind)
    log(f"guided send retry {job.message_id}: {(sent.stderr or sent.stdout).strip()[:200]}")
    return False


def sender_loop():
    failures = 0
    while True:
        guided = outbox_store.jobs()
        if guided:
            if send_guided_job(guided[0]):
                failures = 0
                continue
            failures += 1
            time.sleep(min(60, 5 * failures))
            continue
        legacy = legacy_outbox_files()
        if legacy:
            if send_legacy_outbox_file(legacy[0]):
                failures = 0
                continue
            failures += 1
            if failures == SEND_FAIL_BEEP_AT:
                log_event("send_failed", flow="legacy", reason="send")
                if not _recording and not _guided_active:
                    beep("fail")
            time.sleep(min(60, 5 * failures))
            continue
        failures = 0
        time.sleep(0.5)


_led_last = 0.0
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

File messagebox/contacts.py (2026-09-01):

#!/usr/bin/env python3
"""Authoritative private contact, NFC card, and listener profile store."""

from __future__ import annotations

import argparse
import copy
import fcntl
import json
import math
import os
import posixpath
import pwd
import re
import subprocess
import sys
import tempfile
import time
from contextlib import contextmanager
from pathlib import Path
from typing import Any

from messagebox.runtime_paths import ASSET_DIR, CONTACTS_FILE, NFC_ENROLLMENT_FILE


SCHEMA_VERSION = 2
ASSET_ROOT = str(ASSET_DIR)
MAX_LABEL_LENGTH = 80
MAX_NAME_LENGTH = 80
SERVICE_USER = "messagebox"
ENV_FILE = Path("/etc/messagebox/env")

_GROUP_JID = re.compile(r"^[0-9]+(?:-[0-9]+)?@g\.us$")
_PERSON_JID = re.compile(r"^[0-9]+@s\.whatsapp\.net$")
_UID = re.compile(r"^[0-9A-F]+$")
_LEGACY_ROOT_KEYS = {"version", "revision", "contacts", "listeners"}
_ROOT_KEYS = _LEGACY_ROOT_KEYS | {"default_recipient"}
_CONTACT_KEYS = {
    "label",
    "kind",
    "receive_after",
    "card_uids",
    "card_clip",
}
_LISTENER_KEYS = {"name", "listened_clip"}
JsonObject = dict[str, Any]


class ContactError(ValueError):
    """A safe validation or persistence error suitable for callers to display."""


def _empty_document() -> JsonObject:
    return {
        "version": SCHEMA_VERSION,
        "revision": 0,
        "default_recipient": None,
        "contacts": {},
        "listeners": {},
    }


def _chat_kind(value: object) -> str:
    if not isinstance(value, str):
        raise ContactError("contact JID is invalid")
    if _GROUP_JID.fullmatch(value):
        return "group"
    if _PERSON_JID.fullmatch(value):
        return "person"
    raise ContactError("contact JID is invalid")


def _clean_chat_jid(value: object) -> str:
    if not isinstance(value, str):
        raise ContactError("contact JID is invalid")
    jid = value.strip()
    _chat_kind(jid)
    return jid


def _canonical_listener_jid(value: object) -> str:
    if not isinstance(value, str):
        raise ContactError("listener JID is invalid")
    jid = value.strip().lower()
    if not jid or len(jid) > 320 or jid.count("@") != 1:
        raise ContactError("listener JID is invalid")
    user, server = jid.split("@", 1)
    if ":" in user:
        user = user.split(":", 1)[0]
    if (
        not user
        or not server
        or ":" in server
        or any(character.isspace() for character in user + server)
    ):
        raise ContactError("listener JID is invalid")
    return f"{user}@{server}"


def _clean_text(value: object, field: str, maximum: int) -> str:
    if not isinstance(value, str):
        raise ContactError(f"{field} must be text")
    cleaned = value.strip()
    if not cleaned or len(cleaned) > maximum or "\x00" in cleaned:
        raise ContactError(f"{field} is invalid")
    return cleaned


def _clean_clip(value: object, field: str) -> str:
    if not isinstance(value, str):
        raise ContactError(f"{field} must be text")
    clip = value.strip()
    if not clip:
        return ""
    if "\x00" in clip or not clip.startswith("/") or not clip.endswith(".wav"):
        raise ContactError(f"{field} is invalid")
    normalized = posixpath.normpath(clip)
    if not normalized.startswith(f"{ASSET_ROOT}/"):
        raise ContactError(f"{field} is invalid")
    return normalized


def _clean_receive_after(value: object) -> int | float:
    if type(value) is int:
        if value >= 0:
            return value
    elif type(value) is float and math.isfinite(value) and value >= 0:
        return value
    raise ContactError("receive_after must be a finite nonnegative number")


def _normalize_uid(value: object) -> str:
    if isinstance(value, bytes):
        raw = value.hex().upper()
    elif isinstance(value, str):
        raw = re.sub(r"[\s:\-]", "", value).upper()
    else:
        raise ContactError("card UID must be bytes or hexadecimal text")
    if len(raw) < 8 or len(raw) > 20 or len(raw) % 2 or not _UID.fullmatch(raw):
        raise ContactError("card UID must contain 4 to 10 hexadecimal bytes")
    return ":".join(raw[index : index + 2] for index in range(0, len(raw), 2))


def normalize_card_uid(value: object) -> str:
    """Return the canonical UID stored for a physical card."""
    return _normalize_uid(value)


def validate_contact(jid, label, *, card_clip="") -> JsonObject:
    """Validate contact input without reading or changing the store."""
    jid = _clean_chat_jid(jid)
    return {
        "jid": jid,
        "label": _clean_text(label, "label", MAX_LABEL_LENGTH),
        "kind": _chat_kind(jid),
        "card_clip": _clean_clip(card_clip, "card clip"),
    }


def _validate_document(document: object) -> JsonObject:
    if not isinstance(document, dict):
        raise ContactError("contact store has an invalid schema")
    version = document.get("version")
    if type(version) is not int or version not in {1, SCHEMA_VERSION}:
        raise ContactError("contact store version is unsupported")
    expected_keys = _LEGACY_ROOT_KEYS if version == 1 else _ROOT_KEYS
    if set(document) != expected_keys:
        raise ContactError("contact store has an invalid schema")
    revision = document["revision"]
    if type(revision) is not int or revision < 0:
        raise ContactError("contact store has an invalid revision")
    contacts = document["contacts"]
    listeners = document["listeners"]
    if not isinstance(contacts, dict) or not isinstance(listeners, dict):
        raise ContactError("contact store has an invalid schema")

    seen_uids: set[str] = set()
    for jid, contact in contacts.items():
        kind = _chat_kind(jid)
        if not isinstance(contact, dict) or set(contact) != _CONTACT_KEYS:
            raise ContactError("contact store contains an invalid contact")
        if contact["kind"] != kind:
            raise ContactError("contact store contains an invalid contact kind")
        if _clean_text(contact["label"], "label", MAX_LABEL_LENGTH) != contact["label"]:
            raise ContactError("contact store contains an invalid label")
        _clean_receive_after(contact["receive_after"])
        if _clean_clip(contact["card_clip"], "card clip") != contact["card_clip"]:
            raise ContactError("contact store contains an invalid card clip")
        card_uids = contact["card_uids"]
        if not isinstance(card_uids, list):
            raise ContactError("contact store contains invalid card UIDs")
        for uid in card_uids:
            if not isinstance(uid, str) or _normalize_uid(uid) != uid or uid in seen_uids:
                raise ContactError("contact store contains invalid card UIDs")
            seen_uids.add(uid)
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

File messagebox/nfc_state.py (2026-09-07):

"""Transient NFC state, contact routing, and enrollment workflows."""

from __future__ import annotations

import copy
import fcntl
import json
import os
import tempfile
import time
import uuid
from contextlib import contextmanager
from dataclasses import dataclass
from pathlib import Path
from typing import Any, Callable, Optional

from messagebox.contacts import (
    ContactError,
    ContactStore,
    normalize_card_uid,
    validate_contact,
)
from messagebox.runtime_paths import NFC_ANNOUNCEMENT_FILE


SELECTION_VERSION = 2
ENROLLMENT_VERSION = 1
ANNOUNCEMENT_VERSION = 1
DEFAULT_SELECTION_TTL_S = 30.0
DEFAULT_ENROLLMENT_TTL_S = 300


class NfcError(ValueError):
    """A safe NFC validation or state error suitable for display."""


def normalize_uid(value: object) -> str:
    """Use the contact store's canonical UID representation."""
    try:
        return normalize_card_uid(value)
    except ContactError as exc:
        raise NfcError(str(exc)) from exc


def _atomic_json(path, payload):
    path = Path(path)
    path.parent.mkdir(parents=True, exist_ok=True)
    temporary_path = None
    try:
        with tempfile.NamedTemporaryFile(
            "w",
            encoding="utf-8",
            dir=path.parent,
            prefix=f".{path.name}-",
            delete=False,
        ) as handle:
            temporary_path = Path(handle.name)
            os.chmod(temporary_path, 0o600)
            json.dump(payload, handle, ensure_ascii=False, indent=2, sort_keys=True)
            handle.write("\n")
            handle.flush()
            os.fsync(handle.fileno())
        os.replace(temporary_path, path)
        temporary_path = None
    finally:
        if temporary_path is not None:
            try:
                temporary_path.unlink()
            except FileNotFoundError:
                pass


def _load_json(path, missing=None):
    try:
        with open(path, encoding="utf-8") as handle:
            payload = json.load(handle)
    except FileNotFoundError:
        return missing
    except (OSError, TypeError, ValueError) as exc:
        raise NfcError(f"could not read {Path(path).name}: {exc}") from exc
    if not isinstance(payload, dict):
        raise NfcError(f"{Path(path).name} must contain a JSON object")
    return payload


@contextmanager
def _locked_path(path):
    path = Path(path)
    path.parent.mkdir(parents=True, exist_ok=True)
    lock_path = path.with_name(f".{path.name}.lock")
    with open(lock_path, "a+b") as lock:
        os.fchmod(lock.fileno(), 0o600)
        fcntl.flock(lock.fileno(), fcntl.LOCK_EX)
        try:
            yield
        finally:
            fcntl.flock(lock.fileno(), fcntl.LOCK_UN)


def _public_contact(jid, contact):
    if contact is None:
        return None
    result = {
        "jid": jid,
        **{
            key: copy.deepcopy(value)
            for key, value in contact.items()
            if key != "card_uids"
        },
    }
    result["card_count"] = len(contact["card_uids"])
    result["paired"] = bool(contact["card_uids"])
    return result


def _contact_for_uid(document, uid):
    for jid, contact in document["contacts"].items():
        if uid in contact["card_uids"]:
            return jid, contact
    return None, None
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

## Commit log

2026-08-20 Create first clean open-source candidate
    Source baseline: danpeg/message-box-pi@f5c6329966e689c94dbb190a206a358beb88e1d6. Preserve contributor attribution in AUTHORS.md and the source manifest.
    [source-manifest.tsv]
2026-08-20 Extract dashboard static assets
    [source-manifest.tsv]
2026-08-21 Refactor runtime package and onboarding flow
    [source-manifest.tsv]
2026-08-21 Tighten project documentation
2026-08-23 Add printable Button Box enclosure files (#7)
    [button-box-enclosure-bottom.stl, button-box-enclosure-top.stl]
2026-08-24 Add recipient selection and two-way voice onboarding (#10)
    * feat: add recipient voice onboarding
    * Add NFC tag pairing onboarding (#11)
    * feat: add NFC pairing onboarding
    * assets: add licensed guided reply prompts
    * flow: update instruction
    ---------
2026-08-26 Detect audio devices during setup (#13)
2026-09-01 Unify Button Box dashboard, setup, and caregiver settings (#14)
    Squash-merge the reviewed PR #14 head after local make check (275 tests) and GitHub CI passed. Physical Raspberry Pi acceptance remains a separate gate before customer provisioning.
2026-09-02 docs: clarify reference hardware and enclosures (#16)
2026-09-06 fix: refresh hostname discovery after onboarding
    [completion.py]
2026-09-20 fix: keep recipient chooser open
    [test_runner.py]
2026-09-28 Enclosure README: clear STL and BOM links for EU and US variants (#110)
    * Add EU BOM for the EU S8 enclosure
    Reference parts list for the EU S8 enclosure (EL001 speaker), from the
    frozen BB-PI4-EU-001 design snapshot. Unresolved picks flagged as such.
    — From Muse (Dan's AI assistant)
    * README: clear print-file and BOM links for EU and US enclosure variants
    Both variants now link straight to their print-ready STLs and their BOM:
    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
2026-10-01 Fix SCL wire colour and continuity in the NFC diagram (#128)
